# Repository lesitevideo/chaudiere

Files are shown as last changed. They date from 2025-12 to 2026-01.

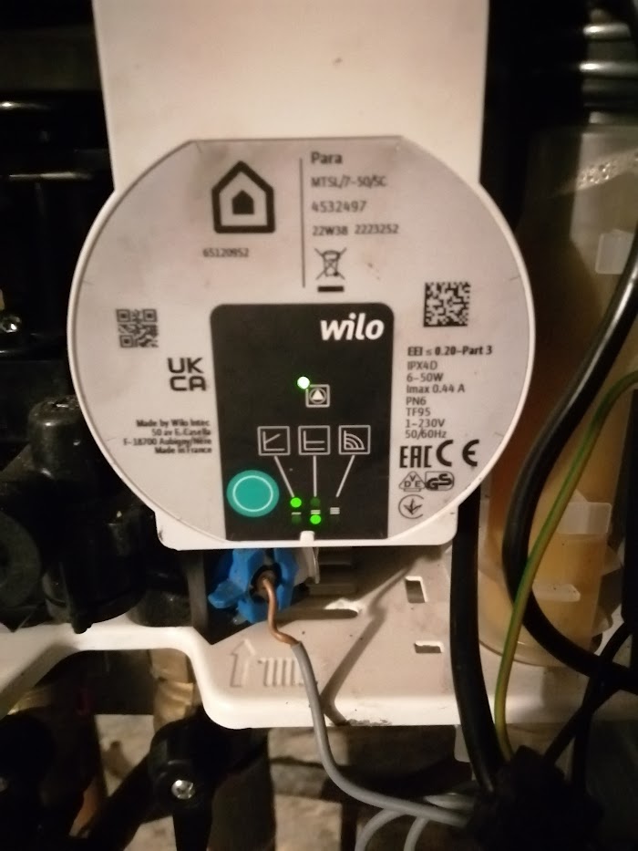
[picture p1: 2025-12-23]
docs/wilo.jpg

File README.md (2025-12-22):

# Contrôle de Chaudière Chaffoteaux MIRA C GREEN

Interface web moderne avec **thermostat automatique** pour contrôler votre chaudière **Chaffoteaux MIRA C GREEN 25** via eBUS (lecture seule) et relais GPIO.







## ✨ Fonctionnalités principales

### 🌡️ Thermostat Automatique (Nouveau !)

- **Capteur DHT22 déporté** - Température et humidité ambiante en temps réel
- **Régulation automatique** par hystérésis (±0.75°C par défaut)
- **Consigne réglable** de 15 à 25°C (interface web)
- **Protection anti-cycles** - Durée minimale configurable entre ON/OFF (7.5 min par défaut)
- **Mode manuel/automatique** - Switch entre contrôle manuel et régulation auto
- **Indicateurs visuels** - État en temps réel (En chauffe, Confort atteint, En attente)
- **Configuration persistante** - Sauvegarde automatique des réglages

### 📊 Monitoring eBUS (Lecture seule)

- **Températures en temps réel** - Départ, retour, ECS, zones
- **État chaudière** - Statut ON/OFF, demandes de chauffage Z1/Z2
- **Diagnostics** - Version ebusd, signal eBUS, maîtres détectés
- **Informations ECS** - Température réelle, mode Comfort

> **Note importante** : Le protocole eBUS sur Mira C Green est **en lecture seule**. L'écriture via BridgeNET n'est pas supportée. Le contrôle se fait exclusivement via le relais GPIO14.

### 🔌 Contrôle GPIO

- **Relais GPIO14** - Contrôle ON/OFF du chauffage via contact TA1 (thermostat)
- **Active-low** - 0 = chauffage ON, 1 = chauffage OFF
- **Mode manuel** - Switch ON/OFF direct depuis l'interface
- **Mode automatique** - Régulation par thermostat DHT22

### 🎨 Interface Web Bootstrap 5

- **Design moderne et responsive** - Optimisé mobile, tablette, desktop
- **Cards élégantes** - Organisation claire par sections
- **Actualisation automatique** - Données rafraîchies toutes les 10 secondes
- **Indicateurs visuels** - Badges colorés, icônes Bootstrap
- **Messages de confirmation** - Alerts Bootstrap pour chaque action

## 🏗️ Architecture

```
┌─────────────────────────────────────────────────────────────┐
│                   Raspberry Pi Principal                     │
│  ┌────────────┐  ┌──────────────┐  ┌──────────────────┐    │
│  │  ebusd     │  │  server.js   │  │   index.html     │    │
│  │  (lecture) │→ │  (Node.js)   │→ │  (Bootstrap 5)   │    │
│  └────────────┘  └──────────────┘  └──────────────────┘    │
│        ↓               ↓                                     │
│   eBUS C6 Stick    GPIO14 (relais)                          │
└────────│───────────────│──────────────────────────────────┘
         │               │
         ↓               ↓
    Chaudière      Contact TA1
    Mira C Green   (thermostat)

┌─────────────────────────────────────────────────────────────┐
│              Raspberry Pi Zero W (Thermostat)               │
│  ┌─────────────────┐                                        │
│  │ dht22-server.py │ ← DHT22 (GPIO4)                       │
│  │   (Python)      │                                        │
│  └─────────────────┘                                        │
│         ↓                                                    │
│  HTTP :5000/data                                            │
└─────────│───────────────────────────────────────────────────┘
          │
          → Réseau local → Raspberry Pi Principal
```

## 🛠️ Matériel requis

### Raspberry Pi Principal

- **Raspberry Pi 3/4** (recommandé) ou Pi Zero 2 W
- **eBUS Adapter Shield C6 Stick Edition** ([lien](https://adapter.ebusd.eu/v5-c6/stick.en.html))
- **Relais 5V** - Module relais 1 canal (active-low compatible)
- **Câbles GPIO** - Connexion GPIO14 → relais → contact TA1 chaudière
- Carte SD 16 Go minimum
- Alimentation 5V 3A

### Raspberry Pi Zero W (Thermostat déporté)

- **Raspberry Pi Zero W** (WiFi intégré)
- **Capteur DHT22** (ou DHT11) - Température et humidité
- Carte SD 8 Go minimum
- Alimentation 5V 1A

### Chaudière

- **Chaffoteaux MIRA C GREEN 25** (ou compatible eBUS/BridgeNET)
- Accès au contact TA1 (thermostat)
- Accès au port eBUS

## 📦 Installation

### 1. Raspberry Pi Principal

```bash
# Cloner le repository
git clone https://github.com/lesitevideo/chaudiere.git
cd chaudiere

# Installer Node.js 20.x
curl -fsSL https://deb.nodesource.com/setup_20.x | sudo bash -
sudo apt install -y nodejs

# Installer ebusd
sudo apt install -y ebusd

# Configurer ebusd
sudo nano /etc/default/ebusd
# EBUSD_OPTS="--device=/dev/ttyUSB0 --scanconfig --latency=10 --port=8888 --httpport=8889"

sudo systemctl enable ebusd
sudo systemctl start ebusd

# Tester ebusd
ebusctl info

# Configurer sudo pour GPIO (nécessaire pour raspi-gpio)
sudo visudo -f /etc/sudoers.d/gpio
# Ajouter (remplacer 'pi' par votre utilisateur):
# pi ALL=(ALL) NOPASSWD: /usr/bin/raspi-gpio set 14 op *
# pi ALL=(ALL) NOPASSWD: /usr/bin/raspi-gpio get 14

# Lancer le serveur
node server.js
```

**Le serveur démarre sur http://[IP]:3000**

### 2. Raspberry Pi Zero W (Thermostat)

Consultez le dossier `thermostat/` pour les fichiers et instructions détaillées.

```bash
# Sur le Pi Zero W
mkdir -p ~/dht22-server
cd ~/dht22-server

# Installer dépendances
sudo apt update
sudo apt install -y python3-pip libgpiod2
sudo pip3 install Flask adafruit-circuitpython-dht adafruit-blinka --break-system-packages

# Créer dht22-server.py (voir thermostat/dht22-server.py)
nano dht22-server.py
chmod +x dht22-server.py

# Créer le service systemd (voir thermostat/thermostat-dht22.service)
sudo nano /etc/systemd/system/thermostat-dht22.service

# Activer et démarrer
sudo systemctl daemon-reload
sudo systemctl enable thermostat-dht22
sudo systemctl start thermostat-dht22

# Vérifier
sudo systemctl status thermostat-dht22
curl http://thermostat-salon.local:5000/data
```

**Configuration hostname du Pi Zero :**
```bash
sudo hostnamectl set-hostname thermostat-salon
```

### 3. Câblage GPIO14 (Relais)

```
Raspberry Pi         Relais 5V           Chaudière
GPIO14 ──────────→ IN
5V ──────────────→ VCC
GND ─────────────→ GND
                    NO ──────────────→ TA1 (contact 1)
                    COM ─────────────→ TA1 (contact 2)
```

**Important** : Utilisez un relais **active-low** ou configurez selon votre module.

## ⚙️ Configuration

### Thermostat (thermostat-config.json)

Créé automatiquement au premier lancement, modifiable via l'interface web :

```json
{
  "enabled": false,
  "targetTemp": 20.0,
  "hysteresis": 1.5,
  "minCycleDuration": 450
}
```

- `enabled` : Mode automatique ON/OFF
- `targetTemp` : Consigne de température (15-25°C)
- `hysteresis` : Écart total en °C (1.5 = ±0.75°C)
- `minCycleDuration` : Délai minimum entre cycles en secondes (450 = 7.5 min)

### ebusd

Fichier `/etc/default/ebusd` :

```bash
EBUSD_OPTS="--device=/dev/ttyUSB0 --scanconfig --latency=10 --port=8888 --httpport=8889"
```

### Serveur Web

Dans `server.js` :

```javascript
const PORT = 3000;
const THERMOSTAT_URL = 'http://thermostat-salon.local:5000/data';
const GPIO_PIN = 14;
```

## 🚀 Utilisation

### Interface Web

Accédez à **http://[IP_RASPBERRY]:3000**

**Sections disponibles :**

1. **Contrôles** :
   - **Thermostat Salon** : Température ambiante, humidité, consigne, mode auto
   - **Marche/Arrêt Chauffage** : Switch manuel (désactivé en mode auto)

2. **État Chaudière** : Statut, demandes Z1/Z2

3. **Températures** : ECS, consignes zones (lecture seule)

4. **Réglages Chaudière (Lecture seule)** : Températures Zone 1 et ECS (informatif)

5. **Informations Système** : Version ebusd, signal eBUS, maîtres

### Mode Thermostat Automatique

1. Régler la consigne (ex: 21°C) avec le slider
2. Activer le **switch "Mode automatique"**
3. Le système régule automatiquement :
   - Chauffe si T < (consigne - 0.75°C)
   - Arrêt si T > (consigne + 0.75°C)
   - Maintien dans la zone d'hystérésis

**Indicateurs d'état :**
- 🔥 **En chauffe** - Relais ON, température insuffisante
- ✅ **Confort atteint** - Relais OFF, température atteinte
- ⏰ **En attente** - Dans la période de protection anti-cycles
- ⚙️ **Mode manuel** - Régulation désactivée

## 🔧 Commandes utiles

```bash
# Vérifier ebusd
sudo systemctl status ebusd
ebusctl info
ebusctl read FlowTemp

# Voir les logs
sudo journalctl -u ebusd -f

# Thermostat Pi Zero W
ssh pi@thermostat-salon.local
sudo systemctl status thermostat-dht22
sudo journalctl -u thermostat-dht22 -f

# Tester thermostat
curl http://thermostat-salon.local:5000/data

# Tester GPIO relais
sudo raspi-gpio get 14
sudo raspi-gpio set 14 op dl  # ON (drive low)
sudo raspi-gpio set 14 op dh  # OFF (drive high)

# Tester API thermostat (depuis Pi principal)
curl http://localhost:3000/api/thermostat/ambient
curl http://localhost:3000/api/thermostat/config
curl http://localhost:3000/api/thermostat/state
curl http://localhost:3000/api/relay/status
```

## 🐛 Dépannage

### Thermostat ne répond pas

```bash
# Vérifier service sur Pi Zero W
ssh pi@thermostat-salon.local
sudo systemctl status thermostat-dht22

# Vérifier réseau
ping thermostat-salon.local

# Tester directement
curl http://thermostat-salon.local:5000/data
```

### Relais ne fonctionne pas

```bash
# Vérifier permissions sudo
sudo raspi-gpio get 14

# Tester manuellement
sudo raspi-gpio set 14 op dl  # ON
sudo raspi-gpio set 14 op dh  # OFF

# Vérifier câblage
# GPIO14 → IN relais
# Vérifier que le relais clique
```

### Erreur "Device or resource busy" (GPIO)

```bash
# Tuer les processus gpioset en conflit
sudo pkill -f gpioset

# Ou reboot
sudo reboot
```

### eBUS ne fonctionne pas

```bash
# Vérifier câblage eBUS (polarité correcte)
# Vérifier USB
ls -la /dev/ttyUSB*

# Permissions
sudo usermod -a -G dialout $USER
sudo usermod -a -G dialout ebusd

# Redémarrer
sudo systemctl restart ebusd
ebusctl info
```

## 🌐 Accès à distance avec Tailscale

**Recommandé** pour un accès distant sécurisé :

```bash
# Sur le Raspberry Pi principal
curl -fsSL https://tailscale.com/install.sh | sh
sudo tailscale up

# Sur le Pi Zero W (optionnel)
curl -fsSL https://tailscale.com/install.sh | sh
sudo tailscale up
```

Puis installez Tailscale sur votre smartphone/PC et accédez via :
```
http://100.xx.xx.xx:3000
```

**Avantages** :
- Chiffrement WireGuard
- Aucun port ouvert
- Gratuit usage personnel
- Multi-plateforme

## 📚 Documentation

- [ebusd Documentation](https://github.com/john30/ebusd)
- [Configuration BridgeNET](https://github.com/ysard/ebusd_configuration_chaffoteaux_bridgenet)
- [Capteur DHT22](https://learn.adafruit.com/dht)
- [Bootstrap 5 Docs](https://getbootstrap.com/docs/5.3/)

## 🗺️ Roadmap

### Fait ✅

- [x] Monitoring eBUS (lecture seule)
- [x] Interface Bootstrap 5 responsive
- [x] Contrôle relais GPIO14
- [x] Thermostat DHT22 déporté (Pi Zero W)
- [x] Régulation automatique avec hystérésis
- [x] Mode manuel/automatique
- [x] Configuration persistante
- [x] Protection anti-cycles
- [x] Indicateurs d'état en temps réel

### À venir 🚧

- [ ] **Sonde température extérieure** - Pour modèle thermique prédictif
- [ ] **Historique et graphiques** - Températures, cycles de chauffe
- [ ] **Apprentissage/prédiction** - Calcul constante thermique, temps de chauffe
- [ ] **Programmation horaire** - Plages de température par jour/heure
- [ ] **Notifications** - Alertes email/push (erreurs, températures)
- [ ] **Authentification** - Login/mot de passe pour sécuriser l'interface
- [ ] **API REST complète** - Documentation OpenAPI/Swagger
- [ ] **Intégration Home Assistant** - Via MQTT ou API REST
- [ ] **Application mobile** - PWA ou native iOS/Android

## ⚠️ Avertissements

- **Utilisez à vos risques** - Modifications de chauffage sensibles
- **Vérifiez le câblage** - Erreur sur TA1 peut endommager la chaudière
- **eBUS lecture seule** - Pas d'écriture possible sur Mira C Green
- **Sécurité électrique** - Relais correctement isolé et dimensionné
- **Consultez le manuel** - De votre chaudière avant toute modification
- **Maintenez à jour** - Système et dépendances

## 📄 Licence

MIT License - Libre d'utilisation et de modification

## 🙏 Remerciements

- [john30](https://github.com/john30) - ebusd
- [ysard](https://github.com/ysard) - Configuration BridgeNET Chaffoteaux
- Communauté eBUS et Raspberry Pi
- Adafruit - Librairies DHT22

---

**Projet développé pour un contrôle moderne et économique de votre chauffage** 🔥

Pour toute question : [Issues GitHub](https://github.com/lesitevideo/chaudiere/issues)

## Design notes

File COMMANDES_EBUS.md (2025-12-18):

# 📋 Commandes eBUS pour Mira C Green BridgeNET

Ce document liste toutes les commandes eBUS utilisées dans l'interface web, basées sur le fichier CSV de configuration `mira_c_green.csv`.

## 🔥 Chauffage - Zone 1

### Lecture (Read)
| Commande | Description | Type |
|---|---|---|
| `water_temp_out` | Température de départ du circuit | Read |
| `water_temp_in` | Température de retour du circuit | Read |
| `ext_temp` | Température extérieure | Read |
| `z1_room_temp` | Température pièce zone 1 | Read |
| `z1_target_temp` | Température cible zone 1 | Read |
| `z1_heating_activation` | État activation chauffage zone 1 | Read |
| `z1_water_max_temp` | Température eau max zone 1 | Read |

### Écriture (Write)
| Commande | Description | Plage | Unité |
|---|---|---|---|
| `z1_day_temp` | Température jour zone 1 | 5-35 | °C |
| `z1_night_temp` | Température nuit zone 1 | 5-35 | °C |
| `z1_fixed_temp` | Température fixe zone 1 | 5-35 | °C |

## 💧 Eau Chaude Sanitaire (DHW)

### Lecture (Read)
| Commande | Description | Type |
|---|---|---|
| `dhw_status` | État activation ECS | Read |
| `dhw_real_temp` | Température réelle ECS | Read |
| `dhw_target_temp` | Température cible ECS | Read |
| `dhw_antifreeze_temp` | Température antigel ECS | Read |
| `dhw_comfort_mode_status` | État mode confort | Read |

### Écriture (Write)
| Commande | Description | Plage | Unité |
|---|---|---|---|
| `dhw_target_temp` | Température cible ECS | 35-65 | °C |
| `dhw_comfort_mode_status_w` | Activer/désactiver mode confort | 0/1 | booléen |

## 📊 État de la Chaudière

### Informations Générales
| Commande | Description | Type |
|---|---|---|
| `boiler_status` | État général de la chaudière | Read |
| `heating_status` | État du chauffage | Read |
| `heating_flame` | État de la flamme | Read |
| `fan_speed` | Vitesse du ventilateur | Read (rpm) |
| `ignition_cycles` | Nombre de cycles d'allumage | Read |

## ⚙️ Paramètres Avancés

### Thermorégulation Zone 1
| Commande | Description | Type |
|---|---|---|
| `z1_thermoreg_slope` | Pente thermorégulation | Read |
| `z1_thermoreg_offset` | Décalage thermorégulation | Read |

### Système SRA
| Commande | Description | Type |
|---|---|---|
| `sra_status` | État du système SRA | Read |
| `boost_time` | Temps boost (secondes) | Read |

### Erreurs
| Commande | Description | Type |
|---|---|---|
| `error_code` | Code d'erreur actuel | Read |

## 🔧 Utilisation avec ebusd

### Format de lecture
```bash
# Via ebusctl
ebusctl read water_temp_out

# Via HTTP API (port 8889)
curl http://localhost:8889/data/water_temp_out
```

### Format d'écriture
```bash
# Via ebusctl
ebusctl write z1_day_temp 21.5

# Via HTTP API (port 8889)
curl http://localhost:8889/data/z1_day_temp/write?21.5
```

## 📝 Notes Importantes

1. **Configuration ebusd** : Assurez-vous que ebusd est configuré avec le fichier CSV `mira_c_green.csv` du dépôt [ebusd_configuration_chaffoteaux_bridgenet](https://github.com/ysard/ebusd_configuration_chaffoteaux_bridgenet)

2. **Port HTTP** : L'interface web utilise le port **8889** pour communiquer avec ebusd

3. **Actualisation** : Les données sont automatiquement actualisées toutes les 30 secondes

4. **Commandes non supportées** : Si une commande retourne "-" ou une erreur, elle peut ne pas être supportée par votre modèle de chaudière

## 🔍 Commandes Supplémentaires Disponibles

Le fichier CSV contient d'autres commandes non utilisées dans l'interface actuelle :

### Zones supplémentaires (Z2-Z7)
- `z2_room_temp`, `z3_room_temp`, etc.
- `z2_target_temp`, `z3_target_temp`, etc.
- `z2_heating_activation`, `z3_heating_activation`, etc.

### Temporisation
- `timer_day_part_1` à `timer_day_part_14`
- Configuration des plages horaires

### Historique d'erreurs
- `error_slot_1_code` à `error_slot_10_code`
- `error_slot_1_date` à `error_slot_10_date`

## 🎯 Pour Aller Plus Loin

Si vous souhaitez ajouter d'autres fonctionnalités :

1. **Multi-zones** : Ajouter le support des zones 2-7
2. **Programmation horaire** : Implémenter les timer_day_part
3. **Historique d'erreurs** : Afficher les 10 dernières erreurs
4. **Graphiques** : Ajouter des graphiques de température
5. **Notifications** : Alertes en cas d'erreur

## 📚 Référence

- [Dépôt ebusd_configuration_chaffoteaux_bridgenet](https://github.com/ysard/ebusd_configuration_chaffoteaux_bridgenet)
- [Documentation ebusd](https://github.com/john30/ebusd)
- [Wiki ebusd](https://github.com/john30/ebusd/wiki)

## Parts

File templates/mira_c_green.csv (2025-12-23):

# type (r[1-9];w;u) | circuit | name | comment | QQ | ZZ | PBSB | ID | field | part (m/s) | type / templates | divider / values | unit | comment | field | part (m/s) | type / templates | divider / values | unit | comment | field | part (m/s) | type / templates | divider / values | unit | comment | field | part (m/s) | type / templates | divider / values | unit | comment | AG | AH
# System broadcast
w | broadcast | ebus_reset | Reset ebus |  | fe | 2034
# Sent every 4 minutes by boiler
# Sent every minute by Easy Control Bus
r | broadcast | cast_slave_addr | Cast slave address |  | fe | 203b |  |  | m | HEX
# Every 120min
r | boiler | boiler_life_time | Boiler life time (min) |  | 3c | 2000 | 50d9 |  | s | IGN:1 |  |  | field value = dict key for HA integration |  | s | UIN |  | min
r | boiler | burner_heat_life_time | Burner heat life time |  | 3c | 2000 | 4bd1 |  | s | IGN:1 |  |  | field value = dict key for HA integration |  | s | UIN | 10 | h
# Explicit read queries
## Misc
r | boiler | heating_flame | Heating in progress |  | 3c | 2000 | 0c19 |  | s | IGN:1 |  |  | field value = dict key for HA integration | onoff | s | onoff
r | boiler | ignition_cycles | Number of ignition cycles |  | 3c | 2000 | 42d8 |  | s | IGN:1 |  |  | field value = dict key for HA integration |  | s | UIN
r | boiler | fan_speed | Fan speed |  | 3c | 2000 | 4013 |  | s | IGN:1 |  |  | field value = dict key for HA integration |  | s | UIN | 100 | rpm
r | boiler | flame_active | Flame active |  | 3c | 2000 | 0e11 |  | s | IGN:1 |  |  | field value = dict key for HA integration | onoff | s | onoff
r9 | boiler | error_slot_9 | Error Slot 9 (last error) |  | 3c | 2002 | 0400 |  | s | error_code |  |  | 7 first bits of byte | zone | s | BI0:7 |  |  |  |  | s | IGN:2 |  |  | Date: YY/MM/DD | year | s | UCH |  |  |  | month | s | UCH |  |  | day | s | UCH |  | time | s | HTM
#r9 | boiler | error_slot_8 | Error Slot 8 |  | 3c | 2002 | 0401 |  | s | error_code |  |  | 7 first bits of byte | zone | s | BI0:7 |  |  |  |  | s | IGN:2 |  |  | Date: YY/MM/DD | year | s | UCH |  |  |  | month | s | UCH |  |  | day | s | UCH |  | time | s | HTM
#r9 | boiler | error_slot_7 | Error Slot 7 |  | 3c | 2002 | 0402 |  | s | error_code |  |  | 7 first bits of byte | zone | s | BI0:7 |  |  |  |  | s | IGN:2 |  |  | Date: YY/MM/DD | year | s | UCH |  |  |  | month | s | UCH |  |  | day | s | UCH |  | time | s | HTM
#r9 | boiler | error_slot_6 | Error Slot 6 |  | 3c | 2002 | 0403 |  | s | error_code |  |  | 7 first bits of byte | zone | s | BI0:7 |  |  |  |  | s | IGN:2 |  |  | Date: YY/MM/DD | year | s | UCH |  |  |  | month | s | UCH |  |  | day | s | UCH |  | time | s | HTM
#r9 | boiler | error_slot_5 | Error Slot 5 |  | 3c | 2002 | 0404 |  | s | error_code |  |  | 7 first bits of byte | zone | s | BI0:7 |  |  |  |  | s | IGN:2 |  |  | Date: YY/MM/DD | year | s | UCH |  |  |  | month | s | UCH |  |  | day | s | UCH |  | time | s | HTM
#r9 | boiler | error_slot_4 | Error Slot 4 |  | 3c | 2002 | 0405 |  | s | error_code |  |  | 7 first bits of byte | zone | s | BI0:7 |  |  |  |  | s | IGN:2 |  |  | Date: YY/MM/DD | year | s | UCH |  |  |  | month | s | UCH |  |  | day | s | UCH |  | time | s | HTM
#r9 | boiler | error_slot_3 | Error Slot 3 |  | 3c | 2002 | 0406 |  | s | error_code |  |  | 7 first bits of byte | zone | s | BI0:7 |  |  |  |  | s | IGN:2 |  |  | Date: YY/MM/DD | year | s | UCH |  |  |  | month | s | UCH |  |  | day | s | UCH |  | time | s | HTM
#r9 | boiler | error_slot_2 | Error Slot 2 |  | 3c | 2002 | 0407 |  | s | error_code |  |  | 7 first bits of byte | zone | s | BI0:7 |  |  |  |  | s | IGN:2 |  |  | Date: YY/MM/DD | year | s | UCH |  |  |  | month | s | UCH |  |  | day | s | UCH |  | time | s | HTM
#r9 | boiler | error_slot_1 | Error Slot 1 |  | 3c | 2002 | 0408 |  | s | error_code |  |  | 7 first bits of byte | zone | s | BI0:7 |  |  |  |  | s | IGN:2 |  |  | Date: YY/MM/DD | year | s | UCH |  |  |  | month | s | UCH |  |  | day | s | UCH |  | time | s | HTM
#r9 | boiler | error_slot_0 | Error Slot 0 |  | 3c | 2002 | 0409 |  | s | error_code |  |  | 7 first bits of byte | zone | s | BI0:7 |  |  |  |  | s | IGN:2 |  |  | Date: YY/MM/DD | year | s | UCH |  |  |  | month | s | UCH |  |  | day | s | UCH |  | time | s | HTM
## DHW settings
r1 | dhw | dhw_status | DHW heating status |  | 3c | 2000 | 0220 |  | s | IGN:1 |  |  | field value = dict key for HA integration | onoff | s | onoff
r3 | dhw | dhw_target_temp | DHW target temp |  | 3c | 2000 | 6126 |  | s | IGN:1 |  |  | field value = dict key for HA integration |  | s | SIN | 10 | °C
r | dhw | dhw_antifreeze_temp | DHW antifreeze temp |  | 3c | 2000 | 6426 |  | s | IGN:1 |  |  | field value = dict key for HA integration |  | s | SIN | 10 | °C
r1 | dhw | dhw_comfort_mode_status_w | DHW comfort mode |  | 3c | 2000 | c028 |  | s | IGN:1 |  |  | field value = dict key for HA integration | dhw_comfort_mode | s | dhw_comfort_mode
r | dhw | celectic_status | Celectic status |  | 3c | 2000 | 0f20 |  | s | IGN:1 |  |  | field value = dict key for HA integration | onoff | s | onoff
## Heat settings
r1 | boiler | heating_status | Heating status |  | 3c | 2000 | 0120 |  | s | IGN:1 |  |  | field value = dict key for HA integration | onoff | s | onoff
r9 | boiler | sra_status | SRA status |  | 3c | 2000 | 0520 |  | s | IGN:1 |  |  | field value = dict key for HA integration | onoff | s | onoff
r2 | boiler | water_temp_out | Water departure temp |  | 3c | 2000 | 6810 |  | s | IGN:1 |  |  | field value = dict key for HA integration |  | s | SIN | 10 | °C
r2 | boiler | water_temp_in | Water return temp |  | 3c | 2000 | 6910 |  | s | IGN:1 |  |  | field value = dict key for HA integration |  | s | SIN | 10 | °C
r1 | boiler | ext_temp | External temp |  | 3c | 2000 | 7647 |  | s | IGN:1 |  |  | field value = dict key for HA integration |  | s | SIN | 10 | °C
r3 | boiler | ext_temp_offset | External temp offset |  | 3c | 2000 | 7426 |  | s | IGN:1 |  |  | field value = dict key for HA integration |  | s | SIN | 10 | °C
r5 | boiler | boost_time | Boost time (s) |  | 3c | 2000 | 602b |  | s | IGN:1 |  |  | field value = dict key for HA integration |  | s | UIN |  | s
## Z1 settings
r1 | boiler | z1_heating_activation | Z1 Activation of the heating |  | 3c | 2000 | 1919 |  | s | IGN:1 |  |  | field value = dict key for HA integration | onoff | s | onoff
r4 | boiler | z1_thermoreg_slope | Z1 Thermoregulation slope |  | 3c | 2000 | 6a71 |  | s | IGN:1 |  |  | field value = dict key for HA integration |  | s | UIN | 100
r2 | boiler | z1_thermoreg_offset | Z1 Thermoregulation offset |  | 3c | 2000 | 6471 |  | s | IGN:1 |  |  | field value = dict key for HA integration |  | s | SIN | 10 | °C
r4 | boiler | z1_room_temp_infl | Z1 Room temp influence |  | 3c | 2000 | c279 |  | s | IGN:1 |  |  | field value = dict key for HA integration |  | s | UCH
r4 | boiler | z1_water_max_temp | Z1 Max water temp |  | 3c | 2000 | 6071 |  | s | IGN:1 |  |  | field value = dict key for HA integration |  | s | SIN | 10 | °C
r4 | boiler | z1_water_min_temp | Z1 Min water temp |  | 3c | 2000 | 6171 |  | s | IGN:1 |  |  | field value = dict key for HA integration |  | s | SIN | 10 | °C
r5 | boiler | z1_day_temp | Z1 Day temperature |  | 3c | 2000 | 6271 |  | s | IGN:1 |  |  | field value = dict key for HA integration |  | s | SIN | 10 | °C
r5 | boiler | z1_night_temp | Z1 Night temperature |  | 3c | 2000 | 6371 |  | s | IGN:1 |  |  | field value = dict key for HA integration |  | s | SIN | 10 | °C
r5 | boiler | z1_thermoreg_type | Z1 Thermoregulation type |  | 3c | 2000 | c079 |  | s | IGN:1 |  |  | field value = dict key for HA integration | thermoreg_type | s | thermoreg_type
r2 | boiler | z1_fixed_temp | Z1 Fixed temp |  | 3c | 2000 | 6571 |  | s | IGN:1 |  |  | field value = dict key for HA integration |  | s | SIN | 10 | °C
r1 | boiler | z1_target_temp | Z1 Target computed temp |  | 3c | 2000 | 6197 |  | s | IGN:1 |  |  | field value = dict key for HA integration |  | s | SIN | 10 | °C
r2 | boiler | z1_room_temp | Z1 Room temperature |  | 3c | 2000 | 7118 |  | s | IGN:1 |  |  | field value = dict key for HA integration |  | s | SIN | 10 | °C
## Z2 settings
#r1 | boiler | z2_heating_activation | Z2 Activation of the heating |  | 3c | 2000 | 1a19 |  | s | IGN:1 |  |  | field value = dict key for HA integration | onoff | s | onoff
#r4 | boiler | z2_thermoreg_slope | Z2 Thermoregulation slope |  | 3c | 2000 | 6a72 |  | s | IGN:1 |  |  | field value = dict key for HA integration |  | s | UIN | 100
#r2 | boiler | z2_thermoreg_offset | Z2 Thermoregulation offset |  | 3c | 2000 | 6472 |  | s | IGN:1 |  |  | field value = dict key for HA integration |  | s | SIN | 10 | °C
#r4 | boiler | z2_room_temp_infl | Z2 Room temp influence |  | 3c | 2000 | c27a |  | s | IGN:1 |  |  | field value = dict key for HA integration |  | s | UCH
#r4 | boiler | z2_water_max_temp | Z2 Max water temp |  | 3c | 2000 | 6072 |  | s | IGN:1 |  |  | field value = dict key for HA integration |  | s | SIN | 10 | °C
#r4 | boiler | z2_water_min_temp | Z2 Min water temp |  | 3c | 2000 | 6172 |  | s | IGN:1 |  |  | field value = dict key for HA integration |  | s | SIN | 10 | °C
#r5 | boiler | z2_day_temp | Z2 Day temperature |  | 3c | 2000 | 6272 |  | s | IGN:1 |  |  | field value = dict key for HA integration |  | s | SIN | 10 | °C
#r5 | boiler | z2_night_temp | Z2 Night temperature |  | 3c | 2000 | 6372 |  | s | IGN:1 |  |  | field value = dict key for HA integration |  | s | SIN | 10 | °C
#r5 | boiler | z2_thermoreg_type | Z2 Thermoregulation type |  | 3c | 2000 | c07a |  | s | IGN:1 |  |  | field value = dict key for HA integration | thermoreg_type | s | thermoreg_type
#r2 | boiler | z2_fixed_temp | Z2 Fixed temp |  | 3c | 2000 | 6572 |  | s | IGN:1 |  |  | field value = dict key for HA integration |  | s | SIN | 10 | °C
#r1 | boiler | z2_target_temp | Z2 Target computed temp |  | 3c | 2000 | 6297 |  | s | IGN:1 |  |  | field value = dict key for HA integration |  | s | SIN | 10 | °C
#r2 | boiler | z2_room_temp | Z2 Room temperature |  | 3c | 2000 | 7218 |  | s | IGN:1 |  |  | field value = dict key for HA integration |  | s | SIN | 10 | °C
# Write queries
# Note : All the following rules are ok with dest addr 0x3c instead of broadcast
## DHW settings
w | dhw | dhw_status | DHW heating status |  | fe | 2020 | 0220 |  | s | onoff
w | dhw | dhw_target_temp | DHW target temp |  | fe | 2020 | 6126 |  | s | SIN | 10 | °C
w | dhw | dhw_antifreeze_temp | DHW antifreeze temp |  | fe | 2020 | 6426 |  | s | SIN | 10 | °C
# naming error 0c28 in original csv instead of c028 ?
w | dhw | dhw_comfort_mode_status_w | DHW comfort mode |  | fe | 2020 | c028 |  | s | dhw_comfort_mode
w | dhw | celectic_status | Celectic status |  | fe | 2020 | 0f20 |  | s | onoff
## Heat settings
w | boiler | heating_status | Heating status |  | fe | 2020 | 0120 |  | s | onoff
w | boiler | sra_status | SRA status |  | fe | 2020 | 0520 |  | s | onoff
w | boiler | ext_temp_offset | External temp offset |  | fe | 2020 | 7426 |  | s | SIN | 10 | °C
w | boiler | boost_time | Boost time (s) |  | fe | 2020 | 602b |  | s | UIN |  | s
## Z1 settings
w | boiler | z1_heating_activation | Z1 Activation of the heating |  | fe | 2020 | 1919 |  | s | onoff
w | boiler | z1_thermoreg_slope | Z1 Thermoregulation slope |  | fe | 2020 | 6a71 |  | s | UIN | 100
# conflict dump_zones_8
w | boiler | z1_thermoreg_offset | Z1 Thermoregulation offset |  | fe | 2020 | 6471 |  | s | SIN | 10 | °C
w | boiler | z1_room_temp_infl | Z1 Room temp influence |  | fe | 2020 | c279 |  | s | UCH
# conflict dump_zones_1 => read only (shown as a sensor | not as a number entity)
#w | boiler | z1_water_max_temp | Z1 Max water temp |  | fe | 2020 | 6071 |  | s | SIN | 10 | °C
w | boiler | z1_water_min_temp | Z1 Min water temp |  | fe | 2020 | 6171 |  | s | SIN | 10 | °C
w | boiler | z1_day_temp | Z1 Day temperature |  | fe | 2020 | 6271 |  | s | SIN | 10 | °C
w | boiler | z1_night_temp | Z1 Night temperature |  | fe | 2020 | 6371 |  | s | SIN | 10 | °C
# conflict in read mode with thermoregulation_1 => switch to write ?
w | boiler | z1_thermoreg_type | Z1 Thermoregulation type |  | fe | 2020 | c079 |  | s | thermoreg_type
w | boiler | z1_fixed_temp | Z1 Fixed temp |  | fe | 2020 | 6571 |  | s | SIN | 10 | °C
w | boiler | z1_room_temp | Z1 Room temperature |  | fe | 2020 | 7118 |  | s | SIN | 10 | °C
## Z2 settings
w | boiler | z2_heating_activation | Z2 Activation of the heating |  | fe | 2020 | 1a19 |  | s | onoff
w | boiler | z2_thermoreg_slope | Z2 Thermoregulation slope |  | fe | 2020 | 6a72 |  | s | UIN | 100
# conflict dump_zones_8
w | boiler | z2_thermoreg_offset | Z2 Thermoregulation offset |  | fe | 2020 | 6472 |  | s | SIN | 10 | °C
w | boiler | z2_room_temp_infl | Z2 Room temp influence |  | fe | 2020 | c27a |  | s | UCH
# conflict dump_zones_1 => read only (shown as a sensor | not as a number entity)
#w | boiler | z2_water_max_temp | Z2 Max water temp |  | fe | 2020 | 6072 |  | s | SIN | 10 | °C
w | boiler | z2_water_min_temp | Z2 Min water temp |  | fe | 2020 | 6172 |  | s | SIN | 10 | °C
w | boiler | z2_day_temp | Z2 Day temperature |  | fe | 2020 | 6272 |  | s | SIN | 10 | °C
w | boiler | z2_night_temp | Z2 Night temperature |  | fe | 2020 | 6372 |  | s | SIN | 10 | °C
# conflict in read mode with thermoregulation_1 => switch to write ?
w | boiler | z2_thermoreg_type | Z2 Thermoregulation type |  | fe | 2020 | c07a |  | s | thermoreg_type
w | boiler | z2_fixed_temp | Z2 Fixed temp |  | fe | 2020 | 6572 |  | s | SIN | 10 | °C
w | boiler | z2_room_temp | Z2 Room temperature |  | fe | 2020 | 7218 |  | s | SIN | 10 | °C
# Broadcast messages
## Broadcast specific messages with data
# Errors
r | boiler | error_code | Error |  | fe | 2004 |  | error_code | s | error_code |  |  |  | zone_status | s | UCH | 00=inactive;02=active;01=zone_inactive;03=z1_active;05=z2_active;07=z1_z2_active
# Every 30s
r | dhw | dhw_real_temp | DHW real temp | 37 | fe | 2010 | 6147 |  | s | U3N | 10 | °C
# Conflict with dhw_real_temp
#r | dhw | dhw_real_temp_boiler_status | DHW real temp and boiler status | 37 | fe | 2010 | 6147 | dhw_real_temp | s | U3N | 10 | °C |  | _c04b | s | IGN:2 |  |  | Boiler status | boiler_status | s | boiler_status
# Every 25s
r | dhw | dhw_comfort_mode_status | DHW comfort mode status | 37 | fe | 2010 | d746 | dhw_comfort_mode_status | s | BCD:2 | 0=off;2=on |  |  | _da46 | s | IGN:2 |  |  | unknown | da46 | s | UIN | 150=UKN |  |  | _dc46 | s | IGN:2 |  |  | unknown | dc46 | s | UIN | 75=UKN |  | _de46 | s | IGN:2 | unknown | de46 | s | UIN | 75=UKN
# Every 5s
# About ‘boiler_status’ repeat : mandatory since we use a template (entity_id will be ebusd_boiler_boiler_status_boiler_status)
r | boiler | boiler_status | Boiler status | 37 | fe | 2010 | c04b | boiler_status | s | boiler_status
# Every 4min
r | boiler | settings_change_counter | Settings change counter | 37 | fe | 2010 | d140 |  | s | UIN
# Every 20s
r | boiler | cast_date | Date and time ; ex : 03:31;08.12.2023 | 37 | fe | 2070 |  | hour | s | VTM |  |  |  | date | s | HDA
## Dump registers into broadcast messages
# Every 5s
r | boiler | heat_request_status_1 | Heating request status z1-z4 | 37 | fe | 2010 | 0191 | z1_heat_request_status | s | BCD:2 | 0=off;1=on |  |  | _0291 | s | IGN:2 |  |  |  | z2_heat_request_status | s | BCD:2 | 0=off;1=on |  |  | _0391 | s | IGN:2 |  |  |  | z3_heat_request_status | s | BCD:2 | 0=off;1=on |  | _0491 | s | IGN:2 |  | z4_heat_request_status | s | BCD:2 | 0=off;1=on
r | boiler | heat_request_status_2 | Heating request status z5-z7 | 37 | fe | 2010 | 0591 | z5_heat_request_status | s | BCD:2 | 0=off;1=on |  |  | _0691 | s | IGN:2 |  |  |  | z6_heat_request_status | s | BCD:2 | 0=off;1=on |  |  | _0791 | s | IGN:2 |  |  |  | z7_heat_request_status | s | BCD:2 | 0=off;1=on
# Every 25s
r | boiler | hot_water_target_temp_1 | Water computed target temp z1-z3 | 37 | fe | 2010 | 6197 | z1_target_temp | s | S3N | 10 | °C |  | _6297 | s | IGN:2 |  |  |  | z2_target_temp | s | S3N | 10 | °C |  | _6397 | s | IGN:2 |  |  |  | z3_target_temp | s | S3N | 10 | °C
r | boiler | hot_water_target_temp_2 | Water computed target temp z4-z6 | 37 | fe | 2010 | 6497 | z4_target_temp | s | S3N | 10 | °C |  | _6497 | s | IGN:2 |  |  |  | z5_target_temp | s | S3N | 10 | °C |  | _6697 | s | IGN:2 |  |  |  | z6_target_temp | s | S3N | 10 | °C
r | boiler | hot_water_target_temp_3 | Water computed target temp z7 | 37 | fe | 2010 | 6797 | z7_target_temp | s | S3N | 10 | °C
# Every 30min
r | boiler | dump_panel | Heating status | 37 | fe | 2020 | 0120 | heating_status | s | BCD | 0=off;1=on |  |  | _0220 | s | IGN:2 |  |  | DHW heating status | dhw_status | s | BCD | 0=off;1=on |  |  | _0520 | s | IGN:2 |  |  | SRA status | sra_status | s | BCD | 0=off;1=on |  | _0b20 | s | IGN:2 | DHW Thermal Cleansing Function | dhw_thermal_cleansing_mode_status | s | BCD | 0=off;1=on
r | boiler | thermoregulation_1 | Thermoregulation type z1-z4 | 37 | fe | 2020 | c079 | z1_thermoreg_type | s | thermoreg_type |  |  |  | _c07a | s | IGN:2 |  |  | Z2 Thermoregulation type | z2_thermoreg_type | s | thermoreg_type |  |  |  | _c07b | s | IGN:2 |  |  | Z3 Thermoregulation type | z3_thermoreg_type | s | thermoreg_type |  |  | _c07c | s | IGN:2 | Z4 Thermoregulation type | z4_thermoreg_type | s | thermoreg_type
r | boiler | thermoregulation_2 | Thermoregulation type z5-z7 ; Room temp influence z1 | 37 | fe | 2020 | c07d | z5_thermoreg_type | s | thermoreg_type |  |  |  | _c07e | s | IGN:2 |  |  | Z6 Thermoregulation type | z6_thermoreg_type | s | thermoreg_type |  |  |  | _c07f | s | IGN:2 |  |  | Z7 Thermoregulation type | z7_thermoreg_type | s | thermoreg_type |  |  | _c279 | s | IGN:2 | Z1 Room temp influence | z1_room_temp_infl | s | UCH
r | boiler | thermoregulation_3 | Room temp influence z2-z5 | 37 | fe | 2020 | c27a | z2_room_temp_infl | s | UCH |  |  |  | _c27b | s | IGN:2 |  |  | Z3 Room temp influence | z3_room_temp_infl | s | UCH |  |  |  | _c27c | s | IGN:2 |  |  | Z4 Room temp influence | z4_room_temp_infl | s | UCH |  |  | _c27d | s | IGN:2 | Z5 Room temp influence | z5_room_temp_infl | s | UCH
r | boiler | thermoregulation_4 | Room temp influence z6-z7 ; Heating request mode z1-z2 | 37 | fe | 2020 | c27e | z6_room_temp_infl | s | UCH |  |  |  | _c27f | s | IGN:2 |  |  | Z7 Room temp influence | z7_room_temp_infl | s | UCH |  |  |  | _c679 | s | IGN:2 |  |  | Z1 Heating request mode | z1_heat_request_mode | s | heat_request_mode |  |  | _c67a | s | IGN:2 | Z2 Heating request mode | z2_heat_request_mode | s | heat_request_mode
r | boiler | thermoregulation_5 | Heating request mode z3-z6 | 37 | fe | 2020 | c67b | z3_heat_request_mode | s | heat_request_mode |  |  |  | _c67c | s | IGN:2 |  |  | Z4 Heating request mode | z4_heat_request_mode | s | heat_request_mode |  |  |  | _c67d | s | IGN:2 |  |  | Z5 Heating request mode | z5_heat_request_mode | s | heat_request_mode |  |  | _c67e | s | IGN:2 | Z6 Heating request mode | z6_heat_request_mode | s | heat_request_mode
#r | boiler | thermoregulation_6 | Heating request mode z7 ; ? | 37 | fe | 2020 | c67f | z7_heat_request_mode | s | heat_request_mode |  |  |  | _c979 | s | IGN:2 |  |  | Z1 |  | s | UCH |  |  |  | _c97a | s | IGN:2 |  |  | Z2 |  | s | UCH |  |  | _c97b | s | IGN:2 | Z3 |  | s | UCH
#r | boiler | thermoregulation_7 | Z4 | 37 | fe | 2020 | c97c |  | s | UCH |  |  |  | _c97d | s | IGN:2 |  |  | Z5 |  | s | UCH |  |  |  | _c97e | s | IGN:2 |  |  | Z6 |  | s | UCH |  |  | _c97f | s | IGN:2 | Z7 |  | s | UCH
r | boiler | heat_temp_ranges_1 | Temp range z1-z4 | 37 | fe | 2020 | 0081 | z1_heat_temp_range | s | BCD | 0=high;1=low |  |  | _0082 | s | IGN:2 |  |  | Z2 Temp range | z2_heat_temp_range | s | BCD | 0=high;1=low |  |  | _0083 | s | IGN:2 |  |  | Z3 Temp range | z3_heat_temp_range | s | BCD | 0=high;1=low |  | _0084 | s | IGN:2 | Z4 Temp range | z4_heat_temp_range | s | BCD | 0=high;1=low
r | boiler | heat_temp_ranges_2 | Temp range z5-z7 | 37 | fe | 2020 | 0085 | z5_heat_temp_range | s | BCD | 0=high;1=low |  |  | _0086 | s | IGN:2 |  |  | Z6 Temp range | z6_heat_temp_range | s | BCD | 0=high;1=low |  |  | _0087 | s | IGN:2 |  |  | Z7 Temp range | z7_heat_temp_range | s | BCD | 0=high;1=low
r | boiler | dump_zones_1 | Max water temp z1-z4 | 37 | fe | 2020 | 6071 | z1_water_max_temp | s | SIN | 10 | °C |  | _6072 | s | IGN:2 |  |  | Z2 Max water temp | z2_water_max_temp | s | SIN | 10 | °C |  | _6073 | s | IGN:2 |  |  | Z3 Max water temp | z3_water_max_temp | s | SIN | 10 | °C | _6074 | s | IGN:2 | Z4 Max water temp | z4_water_max_temp | s | SIN | 10 | °C
r | boiler | dump_zones_2 | Max water temp z5-z7 ; Min water temp z1 | 37 | fe | 2020 | 6075 | z5_water_max_temp | s | SIN | 10 | °C |  | _6076 | s | IGN:2 |  |  | Z6 Max water temp | z6_water_max_temp | s | SIN | 10 | °C |  | _6077 | s | IGN:2 |  |  | Z7 Max water temp | z7_water_max_temp | s | SIN | 10 | °C | _6171 | s | IGN:2 | Z1 Min water temp | z1_water_min_temp | s | SIN | 10 | °C
r | boiler | dump_zones_3 | Min water temp z2-z5 | 37 | fe | 2020 | 6172 | z2_water_min_temp | s | SIN | 10 | °C |  | _6173 | s | IGN:2 |  |  | Z3 Min water temp | z3_water_min_temp | s | SIN | 10 | °C |  | _6174 | s | IGN:2 |  |  | Z4 Min water temp | z4_water_min_temp | s | SIN | 10 | °C | _6175 | s | IGN:2 | Z5 Min water temp | z5_water_min_temp | s | SIN | 10 | °C
r | boiler | dump_zones_4 | Min water temp z6-z7 ; Day temperature z1-z2 | 37 | fe | 2020 | 6176 | z6_water_min_temp | s | SIN | 10 | °C |  | _6177 | s | IGN:2 |  |  | Z7 Min water temp | z7_water_min_temp | s | SIN | 10 | °C |  | _6271 | s | IGN:2 |  |  | Z1 Day temperature | z1_day_temp | s | SIN | 10 | °C | _6272 | s | IGN:2 | Z2 Day temperature | z2_day_temp | s | SIN | 10 | °C
r | boiler | dump_zones_5 | Day temperature z3-z6 | 37 | fe | 2020 | 6273 | z3_day_temp | s | SIN | 10 | °C |  | _6274 | s | IGN:2 |  |  | Z4 Day temperature | z4_day_temp | s | SIN | 10 | °C |  | _6275 | s | IGN:2 |  |  | Z5 Day temperature | z5_day_temp | s | SIN | 10 | °C | _6276 | s | IGN:2 | Z6 Day temperature | z6_day_temp | s | SIN | 10 | °C
r | boiler | dump_zones_6 | Day temperature z7 ; Night temperature z1-z3 | 37 | fe | 2020 | 6277 | z7_day_temp | s | SIN | 10 | °C |  | _6371 | s | IGN:2 |  |  | Z1 Night temperature | z1_night_temp | s | SIN | 10 | °C |  | _6372 | s | IGN:2 |  |  | Z2 Night temperature | z2_night_temp | s | SIN | 10 | °C | _6373 | s | IGN:2 | Z3 Night temperature | z3_night_temp | s | SIN | 10 | °C
r | boiler | dump_zones_7 | Night temperature z4-z7 | 37 | fe | 2020 | 6374 | z4_night_temp | s | SIN | 10 | °C |  | _6173 | s | IGN:2 |  |  | Z5 Night temperature | z5_night_temp | s | SIN | 10 | °C |  | _6376 | s | IGN:2 |  |  | Z6 Night temperature | z6_night_temp | s | SIN | 10 | °C | _6377 | s | IGN:2 | Z7 Night temperature | z7_night_temp | s | SIN | 10 | °C
r | boiler | dump_zones_8 | Thermoregulation offset z1-z4 | 37 | fe | 2020 | 6471 | z1_thermoreg_offset | s | SIN | 10 | °C |  | _6472 | s | IGN:2 |  |  | Z2 Thermoregulation offset | z2_thermoreg_offset | s | SIN | 10 | °C |  | _6473 | s | IGN:2 |  |  | Z3 Thermoregulation offset | z3_thermoreg_offset | s | SIN | 10 | °C | _6474 | s | IGN:2 | Z4 Thermoregulation offset | z4_thermoreg_offset | s | SIN | 10 | °C
r | boiler | dump_zones_9 | Thermoregulation offset z5-z7 ; Fixed temp z1 | 37 | fe | 2020 | 6475 | z5_thermoreg_offset | s | SIN | 10 | °C |  | _6476 | s | IGN:2 |  |  | Z6 Thermoregulation offset | z6_thermoreg_offset | s | SIN | 10 | °C |  | _6477 | s | IGN:2 |  |  | Z7 Thermoregulation offset | z7_thermoreg_offset | s | SIN | 10 | °C | _6571 | s | IGN:2 | Z1 Fixed temp | z1_fixed_temp | s | SIN | 10 | °C
r | boiler | dump_zones_10 | Fixed temp z2-z5 | 37 | fe | 2020 | 6572 | z2_fixed_temp | s | SIN | 10 | °C |  | _6573 | s | IGN:2 |  |  | Z3 Fixed temp | z3_fixed_temp | s | SIN | 10 | °C |  | _6574 | s | IGN:2 |  |  | Z4 Fixed temp | z4_fixed_temp | s | SIN | 10 | °C | _6575 | s | IGN:2 | Z5 Fixed temp | z5_fixed_temp | s | SIN | 10 | °C
#r | boiler | dump_zones_11 | Fixed temp z6-z7 | 37 | fe | 2020 | 6576 | z6_fixed_temp | s | SIN | 10 | °C |  | _6577 | s | IGN:2 |  |  | Z7 Fixed temp | z7_fixed_temp | s | SIN | 10 | °C |  | _6671 | s | IGN:2 |  |  |  |  | s | SIN | 10 | °C | _6672 | s | IGN:2 |  |  | s | SIN | 10 | °C
#r | boiler | dump_zones_12 |  | 37 | fe | 2020 | 6673 |  | s | SIN | 10 | °C |  | _6674 | s | IGN:2 |  |  |  |  | s | SIN | 10 | °C |  | _6675 | s | IGN:2 |  |  |  |  | s | SIN | 10 | °C | _6676 | s | IGN:2 |  |  | s | SIN | 10 | °C
#r | boiler | dump_zones_13 |  | 37 | fe | 2020 | 6677 |  | s | SIN | 10 | °C |  | _6771 | s | IGN:2 |  |  |  |  | s | SIN | 10 | °C |  | _6772 | s | IGN:2 |  |  |  |  | s | SIN | 10 | °C | _6773 | s | IGN:2 |  |  | s | SIN | 10 | °C
#r | boiler | dump_zones_14 |  | 37 | fe | 2020 | 6774 |  | s | SIN | 10 | °C |  | _6775 | s | IGN:2 |  |  |  |  | s | SIN | 10 | °C |  | _6776 | s | IGN:2 |  |  |  |  | s | SIN | 10 | °C | _6777 | s | IGN:2 |  |  | s | SIN | 10 | °C
#r | boiler | dump_zones_15 |  | 37 | fe | 2020 | 6971 |  | s | SIN | 10 | °C |  | _6972 | s | IGN:2 |  |  |  |  | s | SIN | 10 | °C |  | _6973 | s | IGN:2 |  |  |  |  | s | SIN | 10 | °C | _6974 | s | IGN:2 |  |  | s | SIN | 10 | °C
#r | boiler | dump_zones_16 |  | 37 | fe | 2020 | 6975 |  | s | SIN | 10 | °C |  | _6976 | s | IGN:2 |  |  |  |  | s | SIN | 10 | °C |  | _6977 | s | IGN:2 |  |  |  |  | s | SIN | 10 | °C | _6a71 | s | IGN:2 | Z1 Thermoregulation slope | z1_thermoreg_slope | s | UIN | 100
r | boiler | dump_zones_17 | Thermoregulation slope z2-z5 | 37 | fe | 2020 | 6a72 | z2_thermoreg_slope | s | UIN | 100 |  |  | _6a73 | s | IGN:2 |  |  | Z3 Thermoregulation slope | z3_thermoreg_slope | s | UIN | 100 |  |  | _6a74 | s | IGN:2 |  |  | Z4 Thermoregulation slope | z4_thermoreg_slope | s | UIN | 100 |  | _6a75 | s | IGN:2 | Z5 Thermoregulation slope | z5_thermoreg_slope | s | UIN | 100
#r | boiler | dump_zones_18 | Thermoregulation slope z6-z7 ; | 37 | fe | 2020 | 6a76 | z6_thermoreg_slope | s | UIN | 100 |  |  | _6a77 | s | IGN:2 |  |  | Z7 Thermoregulation slope | z7_thermoreg_slope | s | UIN | 100 |  |  | _6b71 | s | IGN:2 |  |  |  |  | s | SIN | 10 | °C | _6b72 | s | IGN:2 |  |  | s | SIN | 10 | °C
#r | boiler | dump_zones_19 |  | 37 | fe | 2020 | 6b73 |  | s | SIN | 10 | °C |  | _6b74 | s | IGN:2 |  |  |  |  | s | SIN | 10 | °C |  | _6b75 | s | IGN:2 |  |  |  |  | s | SIN | 10 | °C | _6b76 | s | IGN:2 |  |  | s | SIN | 10 | °C
#r | boiler | dump_zones_20 |  | 37 | fe | 2020 | 6b77 |  | s | SIN | 10 | °C |  | _6c71 | s | IGN:2 |  |  |  |  | s | SIN | 10 | °C |  | _6c72 | s | IGN:2 |  |  |  |  | s | SIN | 10 | °C | _6c73 | s | IGN:2 |  |  | s | SIN | 10 | °C
#r | boiler | dump_zones_21 |  | 37 | fe | 2020 | 6c74 |  | s | SIN | 10 | °C |  | _6c75 | s | IGN:2 |  |  |  |  | s | SIN | 10 | °C |  | _6c76 | s | IGN:2 |  |  |  |  | s | SIN | 10 | °C | _6c77 | s | IGN:2 |  |  | s | SIN | 10 | °C
r | boiler | timer_prog_1_day_part_1 | Timer Program part 1 | 37 | fe | 2051 | 0007 | day_part_1 | s | HEX:12
r | boiler | timer_prog_2_day_part_2 | Timer Program part 2 | 37 | fe | 2051 | 1007 | day_part_2 | s | HEX:12
r | boiler | timer_prog_3_day_part_1 | Timer Program part 1 | 37 | fe | 2051 | 0107 | day_part_1 | s | HEX:12
r | boiler | timer_prog_4_day_part_2 | Timer Program part 2 | 37 | fe | 2051 | 1107 | day_part_2 | s | HEX:12
r | boiler | timer_prog_5_day_part_1 | Timer Program part 1 | 37 | fe | 2051 | 0207 | day_part_1 | s | HEX:12
r | boiler | timer_prog_6_day_part_2 | Timer Program part 2 | 37 | fe | 2051 | 1207 | day_part_2 | s | HEX:12
r | boiler | timer_prog_7_day_part_1 | Timer Program part 1 | 37 | fe | 2051 | 0307 | day_part_1 | s | HEX:12
r | boiler | timer_prog_8_day_part_2 | Timer Program part 2 | 37 | fe | 2051 | 1307 | day_part_2 | s | HEX:12
r | boiler | timer_prog_9_day_part_1 | Timer Program part 1 | 37 | fe | 2051 | 0407 | day_part_1 | s | HEX:12
r | boiler | timer_prog_10_day_part_2 | Timer Program part 2 | 37 | fe | 2051 | 1407 | day_part_2 | s | HEX:12
r | boiler | timer_prog_11_day_part_1 | Timer Program part 1 | 37 | fe | 2051 | 0507 | day_part_1 | s | HEX:12
r | boiler | timer_prog_12_day_part_2 | Timer Program part 2 | 37 | fe | 2051 | 1507 | day_part_2 | s | HEX:12
r | boiler | timer_prog_13_day_part_1 | Timer Program part 1 | 37 | fe | 2051 | 0607 | day_part_1 | s | HEX:12
r | boiler | timer_prog_14_day_part_2 | Timer Program part 2 | 37 | fe | 2051 | 1607 | day_part_2 | s | HEX:12
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

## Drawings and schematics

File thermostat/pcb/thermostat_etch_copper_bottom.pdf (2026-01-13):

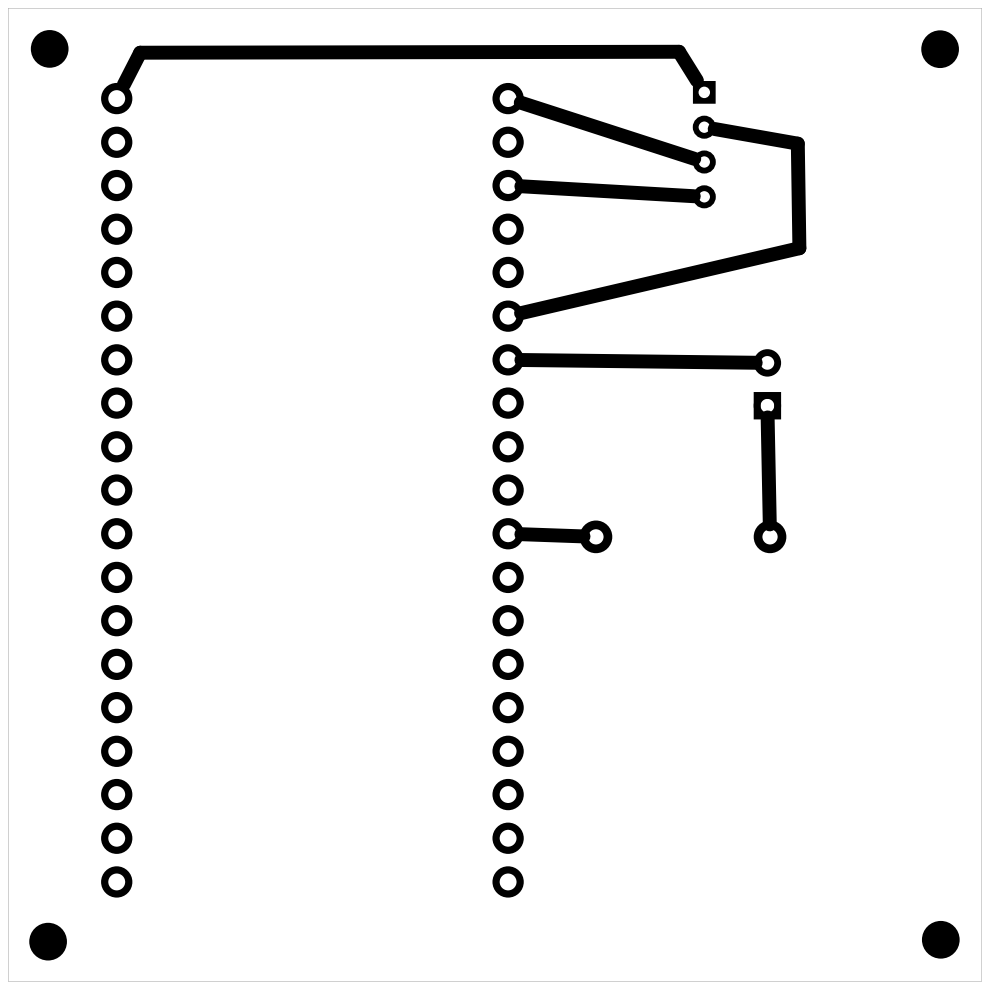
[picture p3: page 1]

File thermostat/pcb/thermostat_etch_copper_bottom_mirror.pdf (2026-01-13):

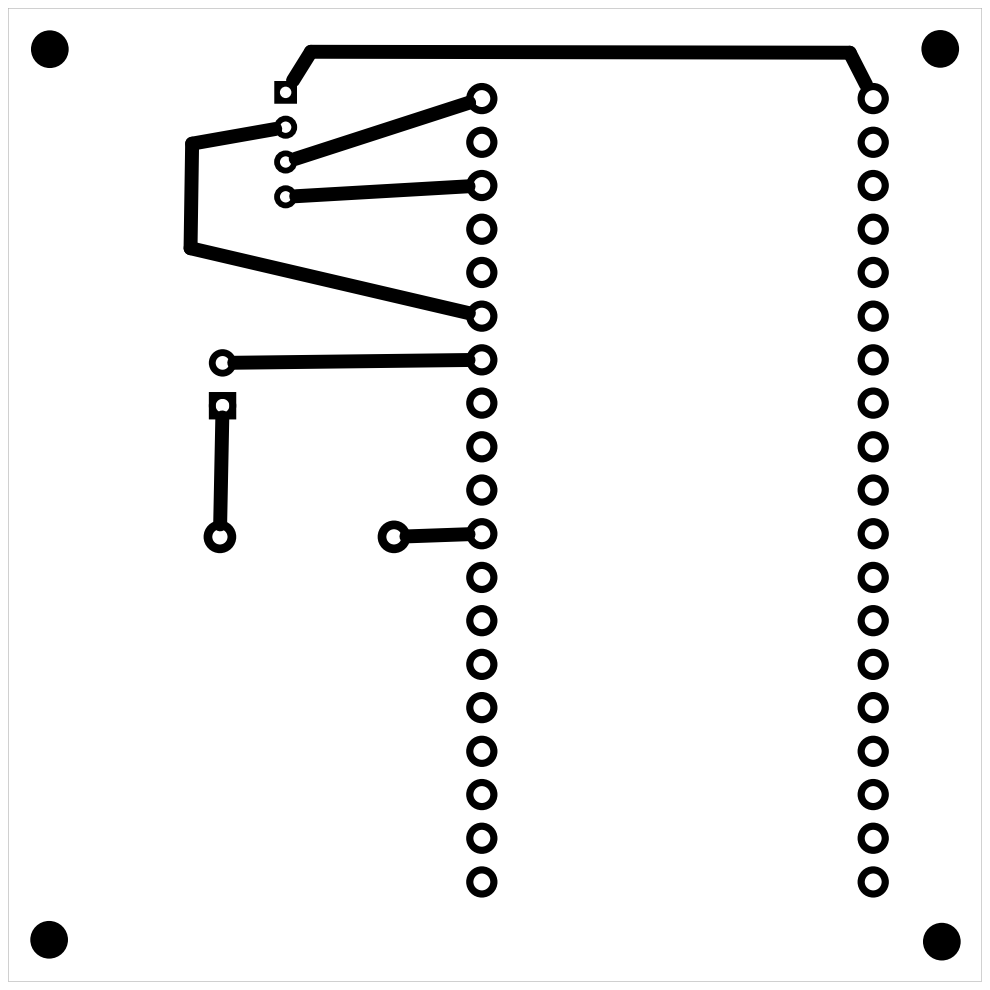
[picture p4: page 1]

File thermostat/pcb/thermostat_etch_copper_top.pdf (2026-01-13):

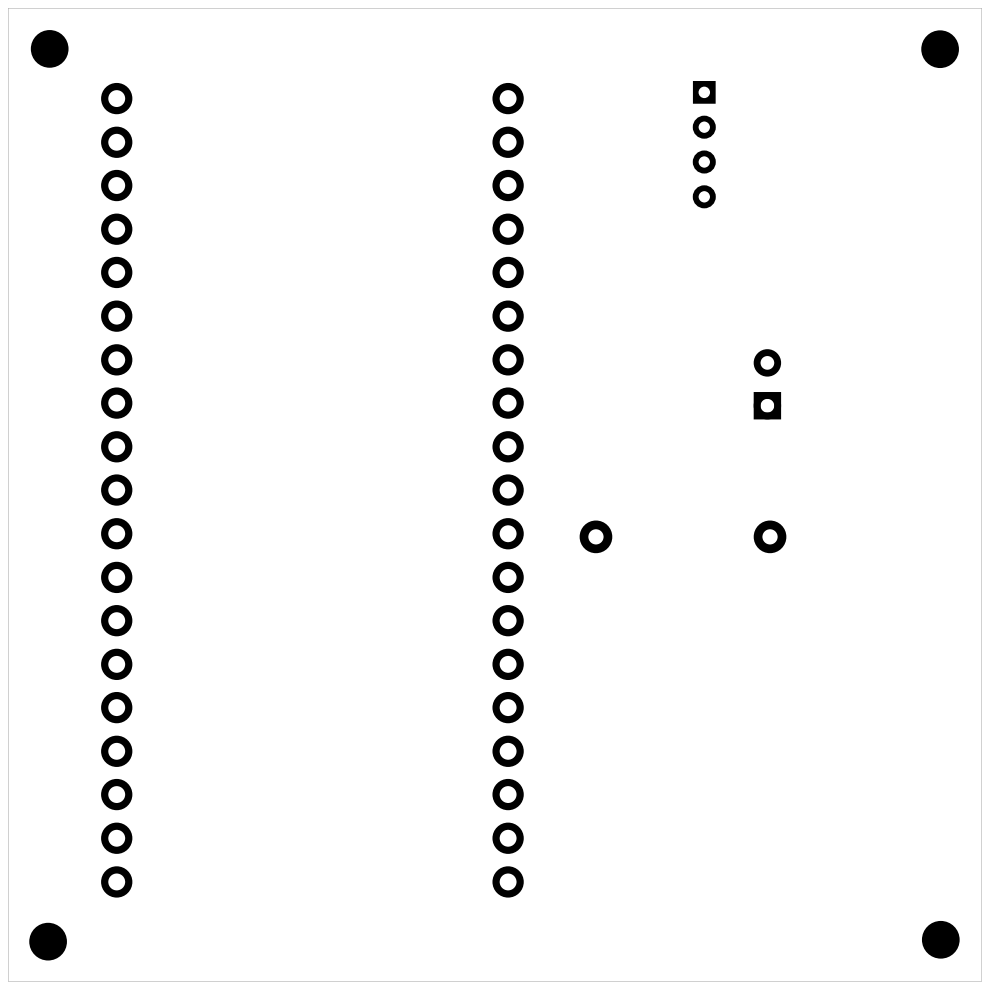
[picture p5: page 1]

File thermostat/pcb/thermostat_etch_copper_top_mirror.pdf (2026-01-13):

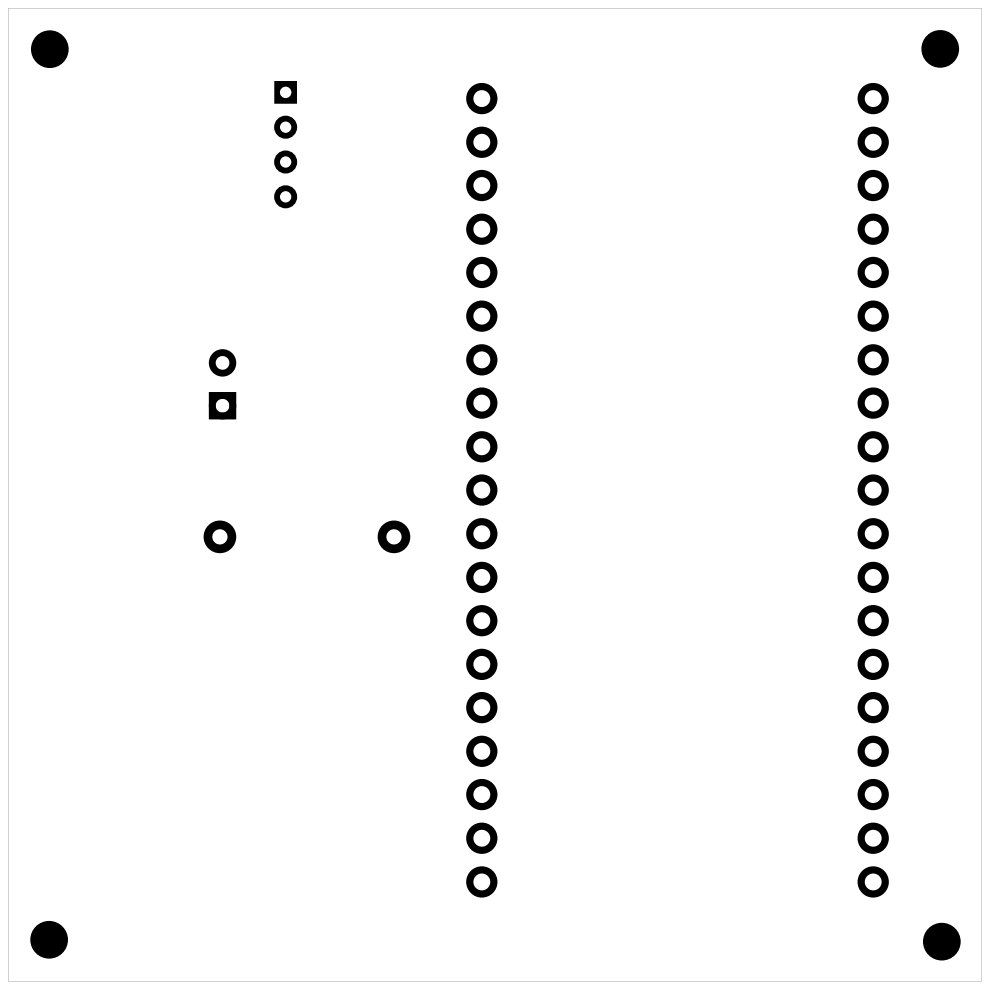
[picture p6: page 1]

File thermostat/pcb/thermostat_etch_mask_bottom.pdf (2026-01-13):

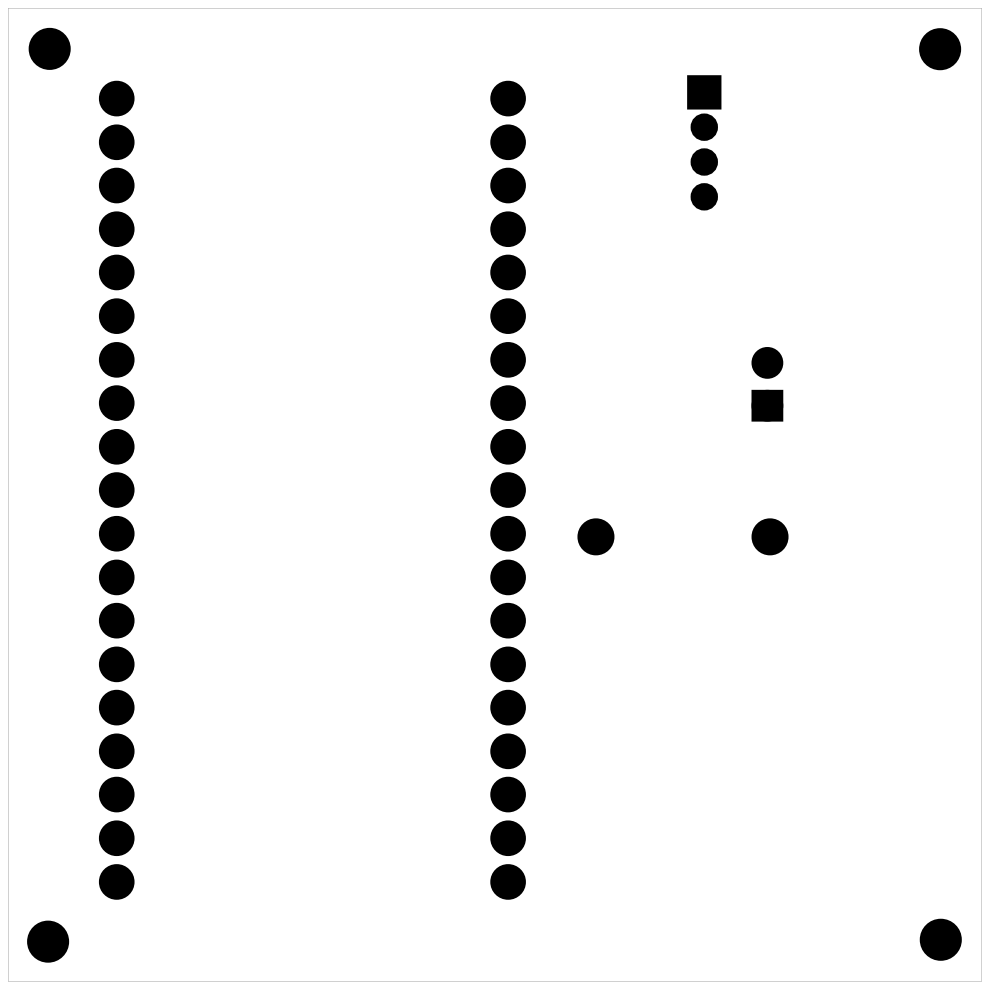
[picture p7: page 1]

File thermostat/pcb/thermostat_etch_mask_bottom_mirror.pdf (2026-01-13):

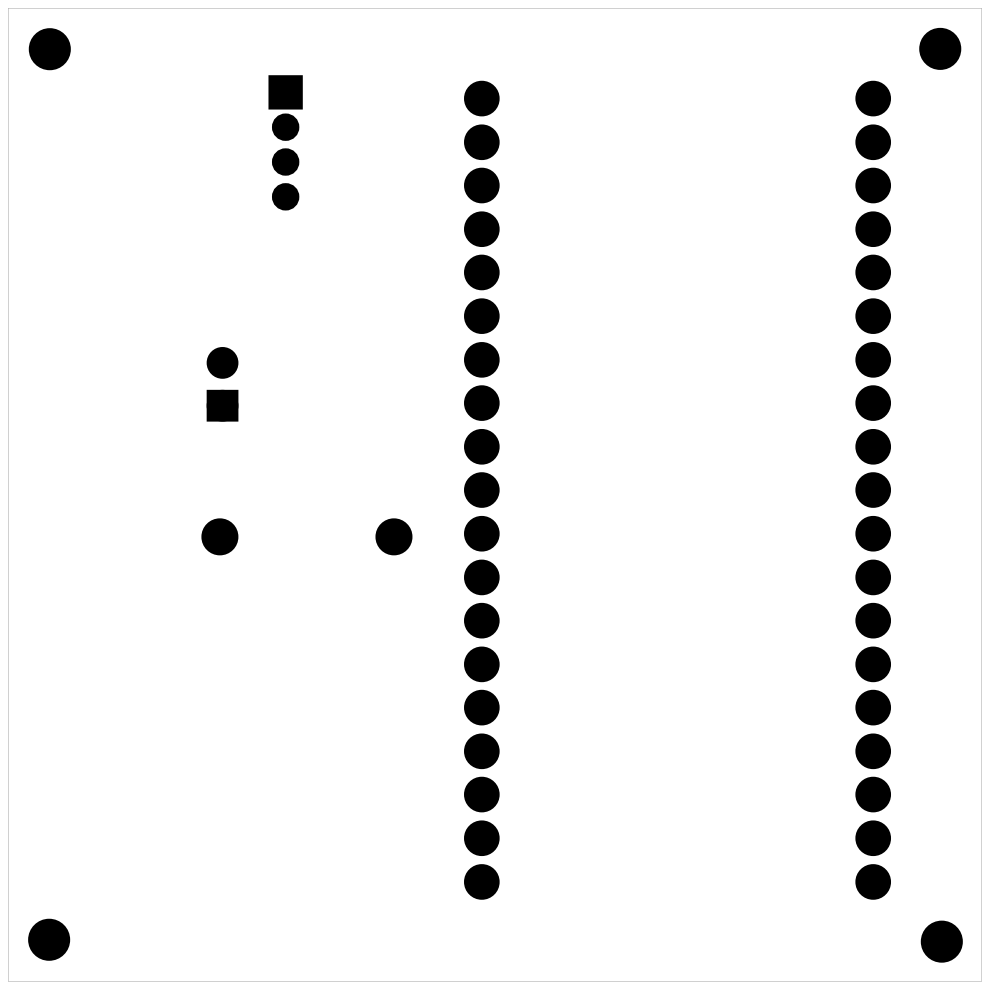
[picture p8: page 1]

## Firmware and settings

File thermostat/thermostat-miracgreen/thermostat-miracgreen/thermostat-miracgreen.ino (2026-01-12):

/*********
  ESP32 + BME280 -> HTTP JSON API with routes
  Routes:
    GET  /         -> same as /data
    GET  /data     -> sensor data + stale detection
    GET  /health   -> running + timestamp
    POST /api/led/heating   JSON: {"state":"on"} or {"state":"off"}
    GET  /api/led/status    -> {"heating":true/false}

  Notes:
  - BME280 read is done in a background task every READING_INTERVAL seconds.
  - timestamp is Unix epoch (UTC) via NTP.
*********/

#include <WiFi.h>
#include <Wire.h>
#include <Adafruit_BME280.h>
#include <Adafruit_Sensor.h>
#include <time.h>
#include <math.h>

#define BME_ADDR 0x76
#define SEALEVELPRESSURE_HPA (1013.25)

// WiFi
const char* ssid     = "Freebox-36E407";
const char* password = "ds3knqrfzvq2rfwnq7n529";
const char* hostname = "thermostat-salon";
// Server
WiFiServer server(80);
const long CLIENT_TIMEOUT_MS = 2000;

// App config (like your Python)
static const int READING_INTERVAL = 60;      // seconds
static const int LED_PIN = 17;              // choose a safe GPIO for your ESP32 board

// Sensor
Adafruit_BME280 bme;

// Shared state
struct SensorData {
  float temperature; // C
  float humidity;    // %
  float pressure;    // hPa
  time_t timestamp;  // epoch
  char status[12];   // "starting" / "ok" / "error" / "stale"
};

static SensorData sensorData = { NAN, NAN, NAN, 0, "starting" };

static bool heatingLed = false;

// Locks (ESP32 / FreeRTOS)
portMUX_TYPE dataMux = portMUX_INITIALIZER_UNLOCKED;
portMUX_TYPE ledMux  = portMUX_INITIALIZER_UNLOCKED;

// ---------- Time ----------
static bool syncTimeNTP(uint32_t maxWaitMs = 15000) {
  configTime(0, 0, "pool.ntp.org", "time.nist.gov");

  uint32_t start = millis();
  time_t now = time(nullptr);
  while (now < 100000 && (millis() - start) < maxWaitMs) {
    delay(250);
    now = time(nullptr);
  }
  return (now >= 100000);
}

// ---------- Helpers: HTTP ----------
static void httpSend(WiFiClient& client, int code, const char* contentType, const String& body) {
  const char* msg = "OK";
  if (code == 200) msg = "OK";
  else if (code == 400) msg = "Bad Request";
  else if (code == 404) msg = "Not Found";
  else if (code == 405) msg = "Method Not Allowed";
  else if (code == 500) msg = "Internal Server Error";

  client.printf("HTTP/1.1 %d %s\r\n", code, msg);
  client.printf("Content-Type: %s; charset=utf-8\r\n", contentType);
  client.println("Connection: close");
  client.printf("Content-Length: %u\r\n", (unsigned)body.length());
  client.println();
  client.print(body);
}

static String jsonNullsError() {
  return String("{\"humidity\":null,\"status\":\"error\",\"temperature\":null,\"pressure\":null,\"timestamp\":null}");
}

static String jsonSensorData() {
  SensorData copy;
  portENTER_CRITICAL(&dataMux);
  copy = sensorData;
  portEXIT_CRITICAL(&dataMux);

  // if timestamp exists, check stale
  time_t now = time(nullptr);
  bool hasTime = (now >= 100000);
  if (copy.timestamp > 0 && hasTime) {
    int age = (int)(now - copy.timestamp);
    if (age > (READING_INTERVAL * 3)) {
      // don't overwrite shared status, just report stale in output like python did
      strncpy(copy.status, "stale", sizeof(copy.status) - 1);
      copy.status[sizeof(copy.status) - 1] = 0;
    }
  }

  // Build JSON (nulls if missing)
  if (copy.timestamp == 0 || isnan(copy.temperature) || isnan(copy.humidity) || isnan(copy.pressure)) {
    // keep status from copy if you want, but you asked for this exact style on error earlier
    // Here we keep "status" meaningful:
    String s = "{";
    s += "\"temperature\":null,";
    s += "\"humidity\":null,";
    s += "\"pressure\":null,";
    s += "\"timestamp\":null,";
    s += "\"status\":\"";
    s += String(copy.status);
    s += "\"}";
    return s;
  }

  String s = "{";
  s += "\"temperature\":" + String(copy.temperature, 2) + ",";
  s += "\"humidity\":"    + String(copy.humidity, 2) + ",";
  s += "\"pressure\":"    + String(copy.pressure, 2) + ",";
  s += "\"timestamp\":"   + String((long)copy.timestamp) + ",";
  s += "\"status\":\""    + String(copy.status) + "\"";
  s += "}";
  return s;
}

static String jsonHealth() {
  time_t now = time(nullptr);
  if (now < 100000) {
    return String("{\"status\":\"running\",\"timestamp\":null}");
  }
  return String("{\"status\":\"running\",\"timestamp\":") + String((long)now) + "}";
}

static String jsonLedStatus() {
  bool isOn;
  portENTER_CRITICAL(&ledMux);
  isOn = heatingLed;
  portEXIT_CRITICAL(&ledMux);

  return String("{\"heating\":") + (isOn ? "true" : "false") + "}";
}

// Very small JSON body parser for {"state":"on"} / {"state":"off"}
static bool parseLedStateFromBody(const String& body, bool& outOn) {
  // Accept "on"/"off" with or without quotes spacing, very forgiving
  String b = body;
  b.toLowerCase();

  int i = b.indexOf("state");
  if (i < 0) return false;

  // Look for "on" or "off"
  if (b.indexOf("on", i) >= 0) { outOn = true;  return true; }
  if (b.indexOf("off", i) >= 0) { outOn = false; return true; }

  return false;
}

static void setHeatingLed(bool on) {
  portENTER_CRITICAL(&ledMux);
  heatingLed = on;
  portEXIT_CRITICAL(&ledMux);

  digitalWrite(LED_PIN, on ? HIGH : LOW);
}

// ---------- Sensor task ----------
void sensorTask(void* pv) {
  (void)pv;

  for (;;) {
    float t = bme.readTemperature();
    float h = bme.readHumidity();
    float p = bme.readPressure() / 100.0F;
    time_t now = time(nullptr);

    bool ok = !isnan(t) && !isnan(h) && !isnan(p) && (now >= 100000);

    portENTER_CRITICAL(&dataMux);
    if (ok) {
      sensorData.temperature = t;
      sensorData.humidity = h;
      sensorData.pressure = p;
      sensorData.timestamp = now;
      strncpy(sensorData.status, "ok", sizeof(sensorData.status) - 1);
      sensorData.status[sizeof(sensorData.status) - 1] = 0;
    } else {
      // keep last good values if you prefer; here we mark error but keep fields as-is
      strncpy(sensorData.status, "error", sizeof(sensorData.status) - 1);
      sensorData.status[sizeof(sensorData.status) - 1] = 0;

      // if no valid time, we also clear timestamp to match your error schema
      if (now < 100000) sensorData.timestamp = 0;
    }
    portEXIT_CRITICAL(&dataMux);

    // Optional debug
    if (ok) {
      Serial.printf("BME280: %.2f°C, %.2f%%, %.2f hPa\n", t, h, p);
    } else {
      Serial.println("BME280: read error or time not synced");
    }

    vTaskDelay(pdMS_TO_TICKS(READING_INTERVAL * 1000));
  }
}

// ---------- HTTP request handling ----------
static bool readRequestLine(WiFiClient& client, String& method, String& path) {
  String line = client.readStringUntil('\n');
  line.trim();
  if (line.length() == 0) return false;

  int sp1 = line.indexOf(' ');
  if (sp1 < 0) return false;
  int sp2 = line.indexOf(' ', sp1 + 1);
  if (sp2 < 0) return false;

  method = line.substring(0, sp1);
  path = line.substring(sp1 + 1, sp2);

  // strip querystring
  int q = path.indexOf('?');
  if (q >= 0) path = path.substring(0, q);

  method.toUpperCase();
  return true;
}

static void handleClient(WiFiClient& client) {
  unsigned long start = millis();

  String method, path;
  if (!readRequestLine(client, method, path)) {
    httpSend(client, 400, "application/json", "{\"error\":\"bad request\"}");
    return;
  }

  int contentLength = 0;

  // Read headers
  while (client.connected() && (millis() - start) < CLIENT_TIMEOUT_MS) {
    String h = client.readStringUntil('\n');
    if (!client.connected()) break;
    h.trim();
    if (h.length() == 0) break; // end headers

    String hl = h;
    hl.toLowerCase();
    if (hl.startsWith("content-length:")) {
      String v = h.substring(strlen("Content-Length:"));
      v.trim();
      contentLength = v.toInt();
    }
  }

  String body = "";
  if (method == "POST" && contentLength > 0) {
    // Read body exactly contentLength bytes (best effort within timeout)
    unsigned long bstart = millis();
    while ((int)body.length() < contentLength && (millis() - bstart) < CLIENT_TIMEOUT_MS) {
      if (client.available()) {
        body += (char)client.read();
      } else {
        delay(1);
      }
    }
  }

  // Routing
  if (method == "GET" && (path == "/" || path == "/data")) {
    httpSend(client, 200, "application/json", jsonSensorData());
    return;
  }

  if (method == "GET" && path == "/health") {
    httpSend(client, 200, "application/json", jsonHealth());
    return;
  }

  if (method == "GET" && path == "/api/led/status") {
    httpSend(client, 200, "application/json", jsonLedStatus());
    return;
  }

  if (path == "/api/led/heating") {
    if (method != "POST") {
      httpSend(client, 405, "application/json", "{\"error\":\"method not allowed\"}");
      return;
    }

    bool on = false;
    if (!parseLedStateFromBody(body, on)) {
      httpSend(client, 400, "application/json", "{\"error\":\"Parametre \\\"state\\\" manquant (on/off)\"}");
      return;
    }

    setHeatingLed(on);
    String resp = String("{\"success\":true,\"state\":\"") + (on ? "on" : "off") + "\"}";
    httpSend(client, 200, "application/json", resp);
    return;
  }

  httpSend(client, 404, "application/json", "{\"error\":\"not found\"}");
}

// ---------- Setup / Loop ----------
void setup() {
  Serial.begin(115200);

  pinMode(LED_PIN, OUTPUT);
  digitalWrite(LED_PIN, LOW);

  if (!bme.begin(BME_ADDR)) { // try 0x77 if needed
    Serial.println("Could not find a valid BME280 sensor, check wiring!");
    while (1) delay(10);
  }

  Serial.print("Connecting to ");
  Serial.println(ssid);

  WiFi.mode(WIFI_STA);
  WiFi.setHostname(hostname);
  WiFi.begin(ssid, password);
  while (WiFi.status() != WL_CONNECTED) {
    delay(500);
    Serial.print(".");
  }

  Serial.println("\nWiFi connected.");
  Serial.print("IP address: ");
  Serial.println(WiFi.localIP());

  bool timeOk = syncTimeNTP();
  Serial.println(timeOk ? "NTP time synced." : "NTP sync failed (timestamp will be null until it works).");

  server.begin();

  // Start sensor background task
  xTaskCreatePinnedToCore(
    sensorTask,
    "sensorTask",
    4096,
    nullptr,
    1,
    nullptr,
    1
  );
}

void loop() {
  // basic WiFi resilience
  if (WiFi.status() != WL_CONNECTED) {
    WiFi.reconnect();
    delay(200);
    return;
  }

  WiFiClient client = server.available();
  if (!client) return;

  Serial.println("New Client.");
  handleClient(client);
  client.stop();
  Serial.println("Client disconnected.\n");
}

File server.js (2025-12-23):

const http = require('http');
const https = require('https');
const fs = require('fs');
const path = require('path');
const { execSync } = require('child_process');

const PORT = 3000;
const HOSTNAME = '0.0.0.0';
const EBUSD_HOST = 'localhost';
const EBUSD_PORT = 8889;

// Configuration GPIO relais
const GPIO_PIN = 14;

// Configuration thermostat
const THERMOSTAT_URL = 'http://thermostat-salon.local:5000/data';
const THERMOSTAT_REFRESH_INTERVAL = 60000; // 60 secondes
const THERMOSTAT_CONFIG_FILE = path.join(__dirname, 'thermostat-config.json');

// Cache données thermostat
let thermostatData = {
    temperature: null,
    humidity: null,
    timestamp: null,
    status: 'disconnected',
    error: null
};

// Configuration thermostat (chargée depuis fichier)
let thermostatConfig = {
    mode: 'auto',  // 'manual', 'auto', 'programmed'
    enabled: false,
    targetTemp: 20.0,
    hysteresis: 1.0,
    minCycleDuration: 600,
    programmedMode: {
        activePreset: 'confort',
        override: null  // { temp, expiresAt }
    },
    presets: {}
};

// État thermostat
let thermostatState = {
    lastRelayChange: null,
    currentAction: 'idle',  // 'heating', 'idle', 'waiting'
    lastError: null
};

// Charger configuration thermostat
function loadThermostatConfig() {
    try {
        if (fs.existsSync(THERMOSTAT_CONFIG_FILE)) {
            const data = fs.readFileSync(THERMOSTAT_CONFIG_FILE, 'utf8');
            thermostatConfig = JSON.parse(data);
            console.log('📋 Configuration thermostat chargée:', thermostatConfig);
        } else {
            saveThermostatConfig();
            console.log('📋 Configuration thermostat initialisée par défaut');
        }
    } catch (error) {
        console.error('❌ Erreur chargement config thermostat:', error.message);
    }
}

// Sauvegarder configuration thermostat
function saveThermostatConfig() {
    try {
        fs.writeFileSync(THERMOSTAT_CONFIG_FILE, JSON.stringify(thermostatConfig, null, 2));
        console.log('💾 Configuration thermostat sauvegardée');
    } catch (error) {
        console.error('❌ Erreur sauvegarde config thermostat:', error.message);
    }
}

// Fonctions de contrôle du relais
function setRelay(on) {
    const level = on ? 'dl' : 'dh';
    try {
        execSync(`sudo raspi-gpio set ${GPIO_PIN} op ${level}`, { stdio: 'inherit' });
        console.log(`Relais ${on ? 'ON' : 'OFF'} (GPIO${GPIO_PIN}=${level})`);
        return true;
    } catch (error) {
        console.error('Erreur relais:', error.message);
        throw error;
    }
}

function getRelayState() {
    try {
        const output = execSync(`sudo raspi-gpio get ${GPIO_PIN}`).toString();
        const match = output.match(/level=(\d+)/);
        if (match) {
            const level = parseInt(match[1]);
            const isOn = (level === 0); // Active-low: 0 = ON
            return isOn;
        }
        return null;
    } catch (error) {
        console.error('Erreur lecture GPIO:', error.message);
        return null;
    }
}

// Fonction pour mettre à jour la LED du thermostat
function updateThermostatLED(state) {
    const ledState = state ? 'on' : 'off';
    const url = new URL('http://thermostat-salon.local:5000/api/led/heating');

    const postData = JSON.stringify({ state: ledState });
    const options = {
        hostname: url.hostname,
        port: url.port || 5000,
        path: url.pathname,
        method: 'POST',
        headers: {
            'Content-Type': 'application/json',
            'Content-Length': Buffer.byteLength(postData)
        },
        timeout: 3000
    };

    const req = http.request(options, (res) => {
        if (res.statusCode === 200) {
            console.log(`💡 LED thermostat: ${ledState.toUpperCase()}`);
        }
    });

    req.on('error', (err) => {
        // Ne pas bloquer si la LED ne répond pas
        console.warn(`⚠️  LED thermostat non disponible: ${err.message}`);
    });

    req.on('timeout', () => {
        req.destroy();
    });

    req.write(postData);
    req.end();
}

// Fonction pour interroger ebusd
function fetchEbusdData(path) {
    return new Promise((resolve, reject) => {
        const options = {
            hostname: EBUSD_HOST,
            port: EBUSD_PORT,
            path: path,
            method: 'GET',
            timeout: 5000
        };

        const req = http.request(options, (res) => {
            let data = '';
            res.on('data', chunk => data += chunk);
            res.on('end', () => {
                try {
                    const parsed = JSON.parse(data);
                    resolve(parsed);
                } catch (err) {
                    reject(new Error('Invalid JSON from ebusd'));
                }
            });
        });

        req.on('error', reject);
        req.on('timeout', () => {
            req.destroy();
            reject(new Error('Request timeout'));
        });
        req.end();
    });
}

// Nettoyer les overrides expirés
function cleanExpiredOverride() {
    if (thermostatConfig.programmedMode.override) {
        const now = Date.now();
        if (now >= thermostatConfig.programmedMode.override.expiresAt) {
            console.log('⏱️  Override expiré, retour au planning');
            thermostatConfig.programmedMode.override = null;
            saveThermostatConfig();
        }
    }
}

// Vérifier si un override est actif
function hasActiveOverride() {
    cleanExpiredOverride();
    return thermostatConfig.programmedMode.override !== null;
}

// Obtenir la température de l'override
function getOverrideTemp() {
    if (hasActiveOverride()) {
        return thermostatConfig.programmedMode.override.temp;
    }
    return null;
}

// Convertir "HH:MM" en minutes depuis minuit
function timeToMinutes(timeStr) {
    const [hours, minutes] = timeStr.split(':').map(Number);
    return hours * 60 + minutes;
}
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

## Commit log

2025-12-18 Mise à jour interface Mira C Green avec commandes BridgeNET
    - Correction des commandes eBUS pour compatibilité avec mira_c_green.csv
    - Ajout contrôle eau chaude sanitaire (DHW) avec température et mode confort
    - Ajout interface à onglets (Chauffage, Eau Chaude, État, Avancé)
    - Ajout informations avancées : flamme, ventilateur, thermorégulation
    - Ajout affichage températures départ/retour, pièce, extérieure
    - Ajout informations diagnostics : cycles allumage, codes erreur, statut SRA
    - Création document COMMANDES_EBUS.md avec référence complète
    - Amélioration UI : design responsive, messages de confirmation
    - Mise à jour README avec nouvelles fonctionnalités et roadmap
    Com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
2025-12-18 Passage au contrôle direct de température eau (mode fixe)
    - Changement de z1_day_temp vers z1_fixed_temp pour contrôle direct
    - Plage de température modifiée : 35-65°C au lieu de 5-35°C
    - Interface simplifiée sans thermorégulation ni sonde externe
    - Titre mis à jour : "Température Eau de Chauffage (Mode Fixe)"
    - Documentation COMMANDES_EBUS.md et README.md mises à jour
    - Valeur par défaut : 50°C (milieu de plage)
    Permet un contrôle simple comme un bouton de chaudière classique.
2025-12-18 Réorganisation de la structure du projet
    Organisation des fichiers en dossiers :
    - docs/ : toute la documentation (INSTALLATION.md, COMMANDES_EBUS.md, etc.)
    - scripts/ : scripts d'installation (install.sh, install-bridgenet-config.sh)
    - systemd/ : fichier de service systemd
    - public/ : fichiers web statiques (index.html)
    - archive/ : anciennes versions (chaudiere-control-bridgenet.html)
    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
2025-12-18 Suppression de tous les emojis du README
2025-12-19 Corrections script d'installation
    - Mise à jour Node.js 18.x → 20.x (LTS, 18.x déprécié)
    - Vérification existence utilisateur ebusd avant ajout au groupe dialout
    - Amélioration gestion d'erreur installation ebusd (dpkg + apt fix-broken)
    - Affichage version ebusd après installation
    Corrige les erreurs d'installation sur Raspberry Pi Bookworm.
2025-12-19 Ajout détection adaptateurs eBUS ESP32 (ttyACM*)
2025-12-19 Correction service systemd : démarrage auto au boot
    - Requires → Wants : dépendance souple (pas d'échec si ebusd lent)
    - Restart=always → Restart=on-failure : redémarre seulement en cas d'erreur
    - Ajout StartLimitInterval/Burst : limite les tentatives de restart
    - Évite l'erreur 'dependency failed' au démarrage
    Le service démarrera automatiquement même si ebusd met du temps.
2025-12-21 Intégration contrôle relais GPIO14 pour ON/OFF chauffage
    - Ajout routes API /api/relay/on, /api/relay/off, /api/relay/status dans server.js
    - Fonctions setRelay() et getRelayState() pour contrôle GPIO14 (active-low)
    - Nouvelle carte 'Marche/Arrêt Chauffage' dans l'interface web
    - Boutons Allumer/Éteindre avec indicateur de statut (point lumineux)
    - Actualisation automatique de l'état du relais toutes les 10s
    - CSS moderne avec animations et feedback visuel
    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
2025-12-21 Fix relais GPIO : passage à la lib onoff pour maintenir l'état
    Problème : gpioset -m exit relâchait le GPIO immédiatement
    - Relais s'allumait brièvement puis s'éteignait
    Solution : Bibliothèque onoff
    - Le GPIO reste actif tant que le processus Node.js tourne
    - Lecture/écriture synchrone (writeSync/readSync)
    - Gestion propre avec cleanup au SIGTERM/SIGINT
    - Plus de 'gremlin' : le relais reste dans l'état demandé
    Ajout dépendance : onoff ^6.0.3
    [server.js]
2025-12-21 Fix relais GPIO: retour à gpioset avec mode signal
    - Suppression de la dépendance onoff (incompatible Node 20)
    - Utilisation de gpioset -m signal pour maintenir l'état du GPIO
    - Gestion des process avec pkill pour basculer entre ON/OFF
    - Active-low: 0=ON, 1=OFF sur GPIO14
    [server.js]
2025-12-21 Simplification GPIO: utilisation du code relay.js qui fonctionne
    - Copie exacte du code de relay.js (execFileSync avec -m exit)
    - Suppression de la logique complexe avec pkill et background processes
    - Pas de sudo requis depuis server.js, sera géré au niveau service
2025-12-21 Appel direct de relay.js depuis server.js
    - setRelay() appelle maintenant 'sudo node relay.js on/off'
    - Utilise le script qui fonctionne au lieu de dupliquer le code
    - Plus simple et plus fiable
2025-12-21 Fix GPIO persistence: utilise gpioset -m signal
    - Remplace -m exit par -m signal pour maintenir l'état GPIO
    - Utilise spawn() en mode détaché pour garder le processus vivant
    - Tue les anciens processus gpioset avant de changer l'état
    - Le GPIO reste maintenant dans l'état défini
2025-12-21 Fix: utilise setsid pour vraie persistance du processus gpioset
    - Remplace spawn() detached par setsid + execSync
    - setsid crée une nouvelle session détachée complètement
    - Empêche execSync dans server.js de tuer le processus gpioset
    - Améliore le pattern pkill pour plus de précision
2025-12-21 Simplifie GPIO: utilise raspi-gpio au lieu de relay.js
    - Remplace les appels à relay.js par raspi-gpio directement
    - setRelay() : sudo raspi-gpio set 14 op dl/dh (active-low)
    - getRelayState() : parse la sortie de raspi-gpio get 14
    - Plus de conflit Device or resource busy
    - Code plus simple et fiable
2025-12-22 Refonte UI avec Bootstrap 5: interface moderne et responsive
    - Intégration Bootstrap 5.3.2 et Bootstrap Icons
    - Système de grille responsive (col-lg-6, col-md-4)
    - Composants Bootstrap: cards, badges, buttons, alerts
    - Classes utilitaires pour spacing et flexbox
    - Switch Bootstrap pour le mode Comfort
    - Alerts dismissibles pour les messages
    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
2025-12-22 3d case thermostat
2025-12-22 Intégration thermostat DHT22 et refonte contrôles
    Backend (server.js):
    - Lecture périodique du thermostat DHT22 (60s)
    - Route /api/thermostat/ambient (température, humidité, statut)
    - Cache des données thermostat
    Frontend (index.html):
    - Card Thermostat Salon: affichage température et humidité ambiante
    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
2025-12-22 Implémentation thermostat automatique avec régulation par hystérésis
    - Logique de régulation avec hystérésis ±0.75°C (1.5°C total)
    - Durée minimale entre cycles: 450s (7.5 minutes)
    - Protection anti-cycles: gestion du délai minimum
    - Mode dégradé: désactivation auto si capteur HS > 5 min
    - Routes API: /api/thermostat/config (GET/POST) et /api/thermostat/state
    - Configuration persistante dans thermostat-config.json
    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
2025-12-22 Fix thermostat heating logic with asymmetric hysteresis
    Problem: Heating continued above target temperature (21.1°C) in auto mode.
    Root cause: The symmetric hysteresis logic allowed heating to continue
    in the hysteresis zone above the target temperature.
    Solution: Implement asymmetric hysteresis:
    - Start heating when: temp < (target - hysteresis)
    - Stop heating when: temp >= target (not target + hysteresis/2)
    This prevents heating above the target temperature while maintaining
    a hysteresis band below the target to avoid rapid cycling.
    Example with target=20°C, hysteresis=0.5:
    - Before: heat between 19.75°C and 20.25°C (symmetric ±0.25°C)
    - After: heat between 19.5°C and 20.0°C (a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
    [server.js]
2025-12-23 Add programmed thermostat modes, presets, and LED control
    This commit implements three major features:
    ## 1. Thermostat LED Control (GPIO 17)
    - Added LED heating indicator on thermostat device
    - New Flask route: POST /api/led/heating (on/off)
    - LED controlled via pigpio on GPIO 17
    - Server automatically updates LED when heating state changes
    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
2025-12-23 Update README: thermostat DHT22, GPIO control, Bootstrap 5
    Major web interface improvements:
    ## New Tabbed Interface
    - Added Bootstrap tabs: "Chaudière" and "Thermostat"
    - Separated boiler controls from thermostat management
    - Clean, organized navigation
    ## Thermostat Tab Features
    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
2025-12-23 Fix white text on white background in thermostat tab
    - Add text-dark class to card sections with white background
    - Fixes visibility issue where text was white-on-white
    - Affects: Mode automatique switch, État du système section
2025-12-23 Fix thermostat consigne display in Chaudière tab
    When in programmed mode with active target (e.g., 21°C), the Chaudière
    tab was still showing the mode auto static value (20°C). This was
    counter-intuitive.
    Changes:
    - Detect when mode is 'programmed' and enabled
    - Fetch actual active target from /api/thermostat/schedule
    - Display the current programmed temperature instead of auto value
    - Add "(Programmé)" label to indicate the mode
    - Disable slider and +/- buttons when in programmed mode (grayed out)
    - Re-enable controls when in auto or manual mode
    The consigne display now accurately reflects the actual active target
    temperature regardless of the mode.
2025-12-23 update html text color
    [PiZeroCase STEP.stl]
2025-12-23 Add climate control section for Zone 1
    Added a new section in the web interface to display climate control
    parameters for Zone 1, useful when an outdoor temperature sensor is
    connected.
    Backend changes (server.js):
    - Add fetchEbusdData() function to query ebusd via HTTP
    - Add /api/climate/zone1 endpoint to fetch climate regulation params
    - Fetches 10 parameters: ext_temp, thermoreg slope/offset/type,
    target temp, water limits, day/night temps, fixed temp
    Frontend changes (index.html):
    - Add "Régulation Climatique Zone 1" section after Temperatures
    - Display outdoor temp, regulation type (fixed/climatic)
    - Show heating curve slope and offset (parallel)
    - Display calculated water target t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
    [server.js]
2025-12-23 Add diagnostics and error monitoring sections
    Extended the web interface with comprehensive boiler diagnostics
    and error tracking capabilities.
    - Add /api/boiler/diagnostics endpoint for 9 diagnostic parameters:
    * heating_flame, flame_active - combustion state
    * ignition_cycles - total ignition count
    * fan_speed - ventilator RPM
    * water_temp_out/in - circuit temperatures (departure/return)
    * boost_time - boost duration
    * boiler_life_time, burner_heat_life_time - runtime hours
    - Add /api/boiler/errors endpoint for last error (slot 9)
    * Returns error_code, zone, date, time
    - Add "Diagnostics Chaudière" section with 4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
    [server.js]
2025-12-23 Fix data extraction from ebusd using correct message structure
    The previous implementation was trying to access ebusd data with the wrong
    path structure. ebusd returns data in the format:
    boiler.messages.MESSAGE_NAME.fields.FIELD_NAME.value
    - Add getEbusValue() helper function to extract values from ebusd structure
    - Fix climate zone1 endpoint to use correct message paths
    - Fix diagnostics endpoint to use correct field names (onoff for boolean fields)
    - Fix errors endpoint to extract all error fields properly
    This should now properly display climate control, diagnostics, and error data.
    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
    [server.js]
2025-12-23 update 3d model
    [PiZeroCase STEP.stl]
2025-12-23 Fix ebusd field names based on actual JSON structure
    Based on actual curl output, corrected all field names:
    - Most numeric values use field name '0' not 'value'
    - z1_thermoreg_type uses 'thermoreg_type' field and returns strings
    like 'basic_on_off' or 'climatic'
    - Many messages have lastup=0 (never updated): heating_flame,
    flame_active, ignition_cycles, fan_speed, boiler_life_time,
    burner_heat_life_time - set these to null
    - error_slot_9 has decodeerror, use error_code message instead
    - Updated frontend to handle string thermoreg type values
    Available data now working:
    - Climate: ext_temp (8.2°C), z1 params, slopes, temps
    - Diagnostics: water_temp_out/in, boost_time
    - Errors: error_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
    [server.js]
2026-01-12 thermostat update
    remplacement du thermostat raspberry pi zero + dht22 par esp32 + bm280
    [PiZeroCase STEP.stl]
2026-01-13 thermostat pcb
    [thermostat.fzz]

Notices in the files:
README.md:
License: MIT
